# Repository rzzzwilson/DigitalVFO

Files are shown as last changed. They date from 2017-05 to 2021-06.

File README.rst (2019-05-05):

Digital VFO
===========
 
About
=====

I'm an amateur radio operator, but since I'm not in the country in which I
earned my licence I can't actually build or operate a transmitter, so I build
receivers and test gear.  I'm working on being able to operate from my
country of residence, but that's another story.

One piece of test gear that would be useful is called a Signal Generator.  This
is a piece of kit that generates a radio signal of a known frequency.  It can
also be used as a VFO (variable frequency oscillator) in a receiver.

The modern way to accurately generate an RF signal is to use the AD9851 DDS chip
which digitally generates a known frequency from a crystal source.  There are 
quite a few people offering small boards using this chip but I like the
`DDS-60 daughterboard <http://midnightdesignsolutions.com/dds60/>`_
from `Midnight Design Solutions <http://midnightdesignsolutions.com/>`_.
All I need to do is use a microcontroller to control the DDS-60 with some
sort of frequency display!

The obvious solution is to use an Arduino and the ubiquitous 16x2 display.
Since the Arduino is a little large and I hoped to put the kit into a small
case I decided to use a
`Teensy microcontroller <https://www.pjrc.com/store/teensy32.html>`_
which is programmable through the Arduino IDE.  It's about 35mm x 18mm!
It's a very capable little microcontroller and is overkill for this project,
but it's what I have at the moment.  I'm working on a
`smaller "generic" design <https://github.com/rzzzwilson/KiCad_Projects/tree/master/Iota>`_
that I can fit into any PCB projects that need smarts.

I got a couple of generic 16x2 displays from
`AliExpress <https://www.aliexpress.com/wholesale?catId=0&initiative_id=SB_20170504210259&SearchText=display+1602>`_.
I got the rotary encoder from
`the same place <https://www.aliexpress.com/wholesale?catId=0&initiative_id=AS_20170504210300&SearchText=rotary+encoder+switch>`_.

Schematic
=========

The latest code runs on this hardware arrangement:

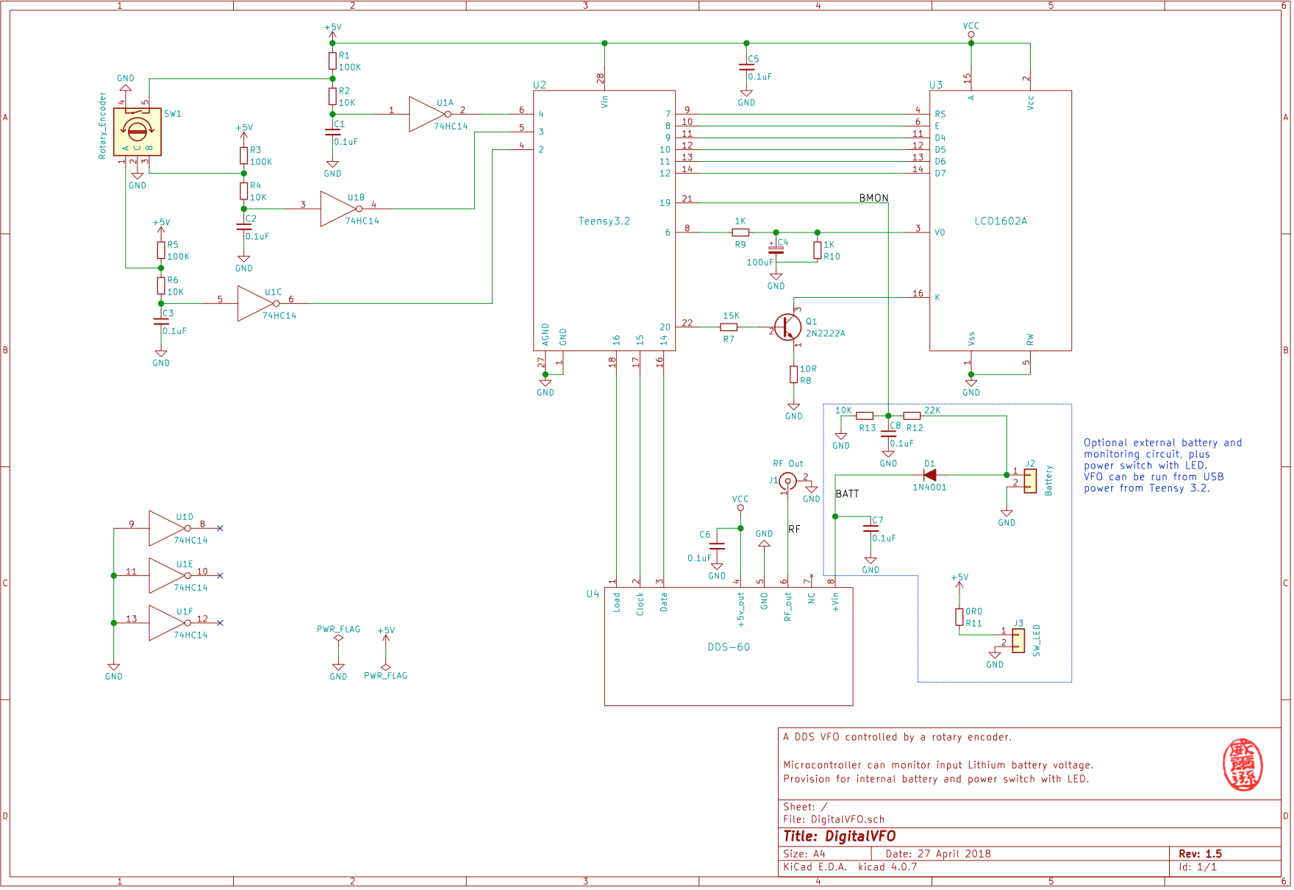
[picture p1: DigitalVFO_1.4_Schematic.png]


PCB
=========

The 1.4 PCB looks like this:

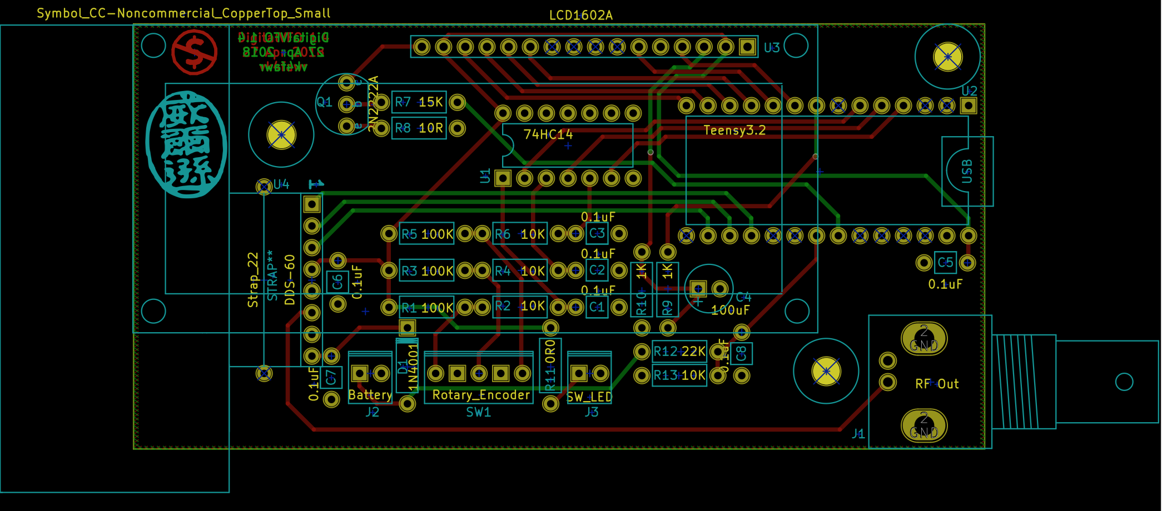
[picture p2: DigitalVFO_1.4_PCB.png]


Status
======

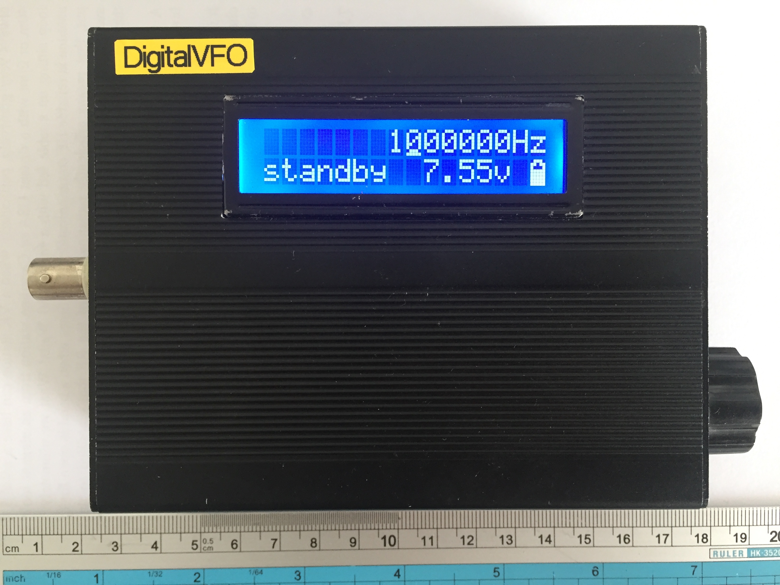
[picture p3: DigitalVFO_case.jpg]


Version 1.4 is running as shown above!  There is provision for a battery plus
monitoring of the voltage and calibration of various things.  There will be another
version called "HeadlessVFO" that will be controlled only by a PC via USB.  This
version won't need a display or rotary encoder, plus it'll always be
connected to a PC and get USB power, so no battery.  I probably don't need
a Teensy 3.2 to drive HeadlessVFO, so I'm searching for cheap microcontrollers
on AliExpress that can accept text commands from the USB connection.

13 Sept: Looking at the AtMega32U4.  A similar chip is used in the Arduino UNO
R3 instead of the FTDI FT232RL USB interface chip, but the AtMega is quite
capable and can control the HeadlessVFO so I won't need any special USB
interface chip.  Anyway, that's the current plan.

Version 1.5
===========

5 May 2019 Update
-----------------

Noted corruption of the display and things like saved frequencies.  The DDS-60
was being set to a **negative** frequency!  Investigated, but suspect this
problem was caused by interference by connecting USB power to the Teensy while
the VFO was running from the battery.  Debug by connecting USB power AT THE PC
while the VFO is off.  See if the problem reoccurs whie doing that.

Early 2019
----------

Modified the PCB layout to include test points for battery voltage, RF out, ground, etc.

Version 1.4
===========

13 September Update
-------------------

The battery arrived but it won't fit into the case.  Instead I'm using the two
18650 test cells with a small BMS PCB, all wrapped in a piece of heat-shrinkable
tubing.  I've bypassed the polarity protection diode as it eats a volt from the
battery.  Working well, but I've found that the power switch I used is a little
unreliable.  That needs to be replaced - the replacement is on a slow boat from
China.

03 July Update
--------------

Still waiting for a 7.4v battery from China.  When it arrives I'll experiment
with the monitoring software.  I may remove the 'polarity' diode once I have
cables made up.  It removes about a volt from the battery and the DDS-60 was
cutting out long before the battery was empty.

21 June Update
--------------

The case is finished.  When/if a permanent battery is installed I'll drill
a few holes for a switch and a 9v charging port.  The software for commands
from the PC is basically finished.  I removed a lot of stuff not necessary
for using the DigitalVFO in an instrument cluster.

19 May Update
-------------

The 1.4 board is back from Seeed, built and operating.  This version has
provision for the micro to sense the battery voltage so it can display
a battery symbol with full/empty options.
Software development time!

Version 1.3
===========

A redesign to use another BNC connecter as the first was junk.
Not sent to Seeed as I also decided to add battery monitoring.

Version 1.2
===========

After building the v1.1 PCB and paddling around on aliexpress.com to find
different components, I'm starting on the v1.2 PCB.  Should be smaller, have
the LCD located in a more natural place and place controls in more natural 
positions.  May also rethink the power supply - perhaps run both board and
DDS-60 from a 78L05 instead of running 9v to DDS-60 and using the onboard
regulator to generate 5v for the main board.  Use the same case as before.

29 March Update
---------------

Version 1.2 of the PCB submitted to Seeed today.  Changes were:

* moved components around to minimize vias
* on-board BNC socket, saves on internal cables
* moves Teensy to edge so USB goes through case, saves on internal cables
* added provision for internal 2s Li-Ion battery and manager PCB feeding the DDS-60
* added provision for LED power in battery power switch

Version 1.1
===========

Need to:

* new case allows in-case programming
* new case has ventilation (passive at first)
* better packaging (printed circuit board)
* better, more linear, contrast control

And, of course:

* allow control over USB
* maybe add a "sweep" function to the in-case code (from, to, step, pause)
* look for bugs in the software

With PC control we can measure things with a "sweep" function.  Allow the PC to
control the VFO frequency and the PC can sweep the frequency to whatever limits
required.  At the same time, measure voltage/current/whatever from other Teensy
instruments.  This means we could build:

* an antenna analyzer
* measure filter response curves
* etc

This version will use a printed circuit board to address the general
unreliability of the 1.0 version.  The LCD will plug into the back of the main
PCB and the DDS-60 will plug into the front.  The rotary encoder will have a
cable with header that will plug into the PCB.

The file **DigitalVFO_Schematic_1.1.pdf** is the schematic of the circuit.  The
directory **kicad/DigitalVFO/Gerbers** holds the output files produced by KiCad.
The Gerber files were sent to a Chinese PCB fab factory.

The PCB has now returned from China, and it does look good.  Better yet,
assembling the board and testing it shows the thing WORKS!  I had to change the
code to match changes I made while setting out the PCB, BUT IT WORKS!!

Version 1.0
===========

The VFO hardware is complete.  Everything is inside a small metal case.  Perhaps
too small a metal case as running at 12v the thing overheats and becomes
unreliable.  It seems OK at 9v.  I also didn't think about accessing the Teensy
USB port when the case is closed, so I can't tweak the software without cracking
the case, which I can't do often as the wiring inside is fragile.

Completed:

* Interface display to teensy, test writing, etc
* Interface rotary encoder, get rotate and button press events
* Basic display of 8-digit frequency
* Implement a simple 'event' system to produce system events
* Get frequency column select and increment/decrement working
* Save state in the EEPROM, restore state on start up
* implement a simple menu system 
* extend the menu system to allow extra functionality
* added vfo_DClick double-click event
* add code to toggle standby/ON mode (from vfo_DClick)
* add in the DDS-60 control code
* add a "Calibrate" setting to adjust the divider value in the DDS-60 code
* test the thing fully!
* make up a metal case and rebuild into it

Perhaps:

* make another case with USB access
* think about making a circuit board for it (Fritzing, cheap Chinese PCB maker?)

Ongoing:

* look for bugs in the software
* maybe add a "sweep" function to the code (from, to, step, pause)
* split out the Arduino code samples showing RE handling and menu system
* think about hardware assembly methods to make DigitalVFO version 2!

Interface
=========

I don't need a lot of functionality in this VFO, I just want to:

* set a frequency from 1.000000Mz to 30.000000MHz with steps down to 1Hz
* save and restore a number of frequencies

It should be possible to do all this with an interface made up of:

* A 16x2 display, and
* A rotary encoder, with switch.

Using the above the user can move a 'column selection' indication in the
frequency display by pressing down on the encoder knob and then rotating it.
With the knob up, rotation just increments or decrements the
selected digit with over- and under-flow occurring to the left of the
selected digit.  This is pretty much the way everybody does it.

It would also be nice if the VFO remembered the frequency and selected digit if
the power is lost and then restored.  Use the on-board EEPROM for this, as well
as remembered frequencies.

We may have to come up with some way of having a simple menu-driven method
of:

* Saving/restoring frequencies
* Adjusting various internal parameters such as clock scaling, etc.

We could possibly drop into the menu system if the encoder knob is held down
for some length of time.

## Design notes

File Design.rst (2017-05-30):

Digital VFO Design
==================

The main hardware components for the VFO are:

+-----------------+-------------------------------------------+
| Microcontroller | Controls the VFO.                         |
+-----------------+-------------------------------------------+
| Rotary encoder  | Allows the user to change VFO frequency   |
|                 | as well as save/restore frequencies, etc. |
+-----------------+-------------------------------------------+
| LCD display     | Display the VFO frequency as well as show |
|                 | the menus, etc.                           |
+-----------------+-------------------------------------------+
| DDS-60 VFO      | Generates the desired VFO frequency.      |
+-----------------+-------------------------------------------+

Operation
---------

The VFO has two modes: 'ONLINE' and 'standby'.

The displayed frequency will be changed by turning the rotary encoder knob to
the left or the right.  This will decrease and increase respectively the
frequency digit under the cursor.  Any overflow or underflow of the selected
digit will propagate to the left only.  Note that even though the displayed
frequency may change, the DDS frequency will change only if the VFO is
ONLINE.

The selection cursor will be moved left or right by pressing in and
holding the rotary encoder knob and rotating the knob to the left or right
while pressed.

The menu will be shown after the rotary encoder knob is held down for a
configurable time without rotation.  When the knob is released the menu will
be shown.  Rotating the knob left and right will navigate through menu choices.

To action a menu item press the rotary encoder knob in for a short press.

To go back one menu level just perform a long press.

Rotary Encoder interrupts
-------------------------

The rotary encoder (RE) is the heart of the VFO.  It has three pins that can
interrupt the microcontroller.  The RE code is entirely interrupt driven and the
raw hardware interrupts handled are:

+--------------+---------------------------+
| Pin          | Interrupt type            |
+==============+===========================+
| pin_A        | on rising edge            |
+--------------+---------------------------+
| pin_B        | on rising edge            |
+--------------+---------------------------+
| pin_Push     | on rising or falling edge |
+--------------+---------------------------+

The code handling these interrupts converts them into simpler logical RE events:

+--------------+------------+
| Action       | RE Event   |
+==============+============+
| Rotate left  | re_RLeft   |
+--------------+------------+
| Rotate right | re_RRight  |
+--------------+------------+
| Knob up      | re_Up      |
+--------------+------------+
| Knob down    | re_Down    |
+--------------+------------+

A further level of RE code takes the above raw RE events and adds
further logical events to get a set of VFO events:

+-------+---------------+-------------------------------------------+
| Value | Event Name    | Description                               |
+=======+===============+===========================================+
|   0	| vfo_None      | No event                                  |
+-------+---------------+-------------------------------------------+
|   1	| vfo_RLeft     | Simple rotation left while switch UP      |
+-------+---------------+-------------------------------------------+
|   2	| vfo_RRight    | Simple rotation right while switch UP     |
+-------+---------------+-------------------------------------------+
|   3	| vfo_DnRLeft   | Rotation left while switch DOWN           |
+-------+---------------+-------------------------------------------+
|   4	| vfo_DnRRight  | Rotation right while switch DOWN          |
+-------+---------------+-------------------------------------------+
|   5	| vfo_Click     | Click of the switch without rotation      |
+-------+---------------+-------------------------------------------+
|   6	| vfo_HoldClick | Held click of the switch without rotation |
+-------+---------------+-------------------------------------------+
|   7	| vfo_DClick    | Double click within a certain period      |
+-------+---------------+-------------------------------------------+

The mapping between the RE events and VFO events is explained below:

+-----------+------------------------------------------------------------------------------+
| RE Event  | Mapping to VFO events                                                        |
+===========+==============================================================================+
| re_RLeft  | If knob is up -> vfo_RLeft, if down -> vfo_DnRLeft.                          |
+-----------+------------------------------------------------------------------------------+
| re_RRight | If knob is up -> vfo_RRight, if down -> vfo_DnRRight.                        |
+-----------+------------------------------------------------------------------------------+
| re_Down   | Set internal state to 'down' and take note of the current millisecond value. |
+-----------+------------------------------------------------------------------------------+
| re_Up     | If elapsed 'down' time is short -> vfo_Click, else -> vfo_HoldClick.         |
|           | If there was any rotation while down no event posted.  Clear 'down' state.   |
|           | If a particular single click was close enough to the previous single click   |
|           | issue a vfo_DClick instead.                                                  |
+-----------+------------------------------------------------------------------------------+

The above implies that there will be internal state to the RE code encapsulating:

* switch state
* time when knob pressed

Event Queue
-----------

The RE code is entirely interrupt driven and a decision was made **not** to
directly drive the VFO logic from interrupt code.  We do this by having the RE
code generate the events above and place them into an event queue.

There will be two functions to push/pop events onto and off the queue::

    push_event(event);
    event = pop_event();

Note that the RE code will never **push** a *vfo_None* event onto the queue.
The *pop_event()* function will return a *vfo_None* event if the queue is empty.

The queue will be implemented as a circular buffer with length of about
10 events.  Note that the *pop_event()* function *must* be thread safe.
The *push_event()* function runs in the interrupt handler so is safe.

Main Event loop
---------------

There will be a main event loop within the Arduino *setup()* function to handle
most top-level interaction.  There will be some smaller event loops within some
menu action handler routines.

Menu System
===========

There will be a menu system that will allow the user to:

* Save/Restore/Delete slots.  Slots hold frequency and other information.
* Reset certain parameters that render the UI unusable, such as brightness, contrast, etc.
* Reset all slots and set configurable parameters to the defaults.
* Configure certain values for brightness, contrast, etc.
* Calibrate the VFO oscillator.
* Etc.

The menu system will have this structure::

    Menu      Slots     Save slot
                        Restore slot
                        Delete Slot
              Settings  Brightness
                        Contrast
                        Hold click
                        Double click
                        Calibrate
              Reset all No
                        Yes
              Credits

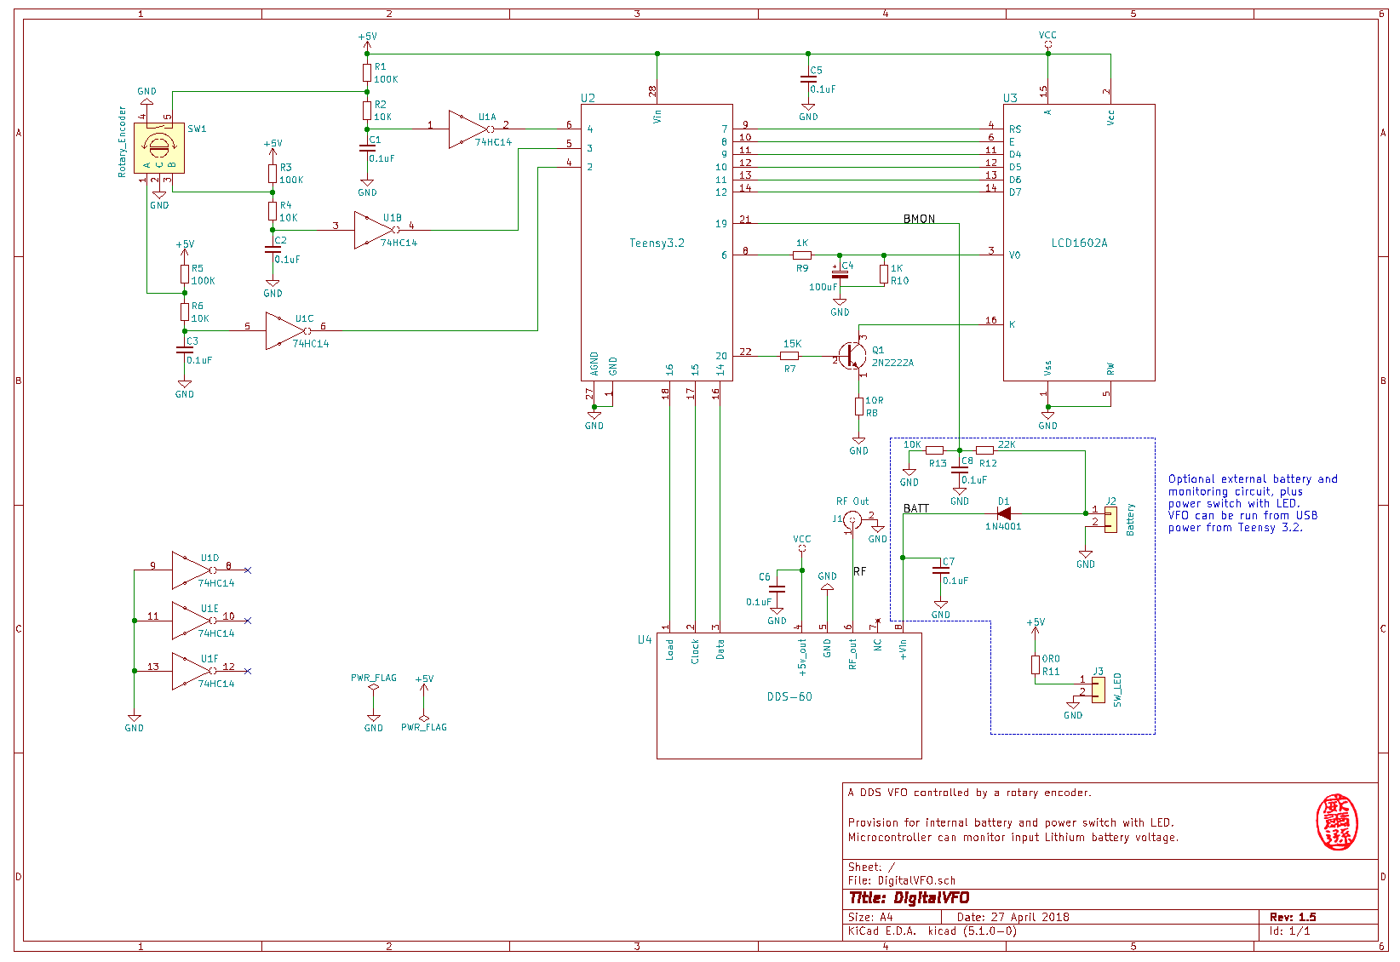
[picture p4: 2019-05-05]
DigitalVFO_1.5_Schematic.png

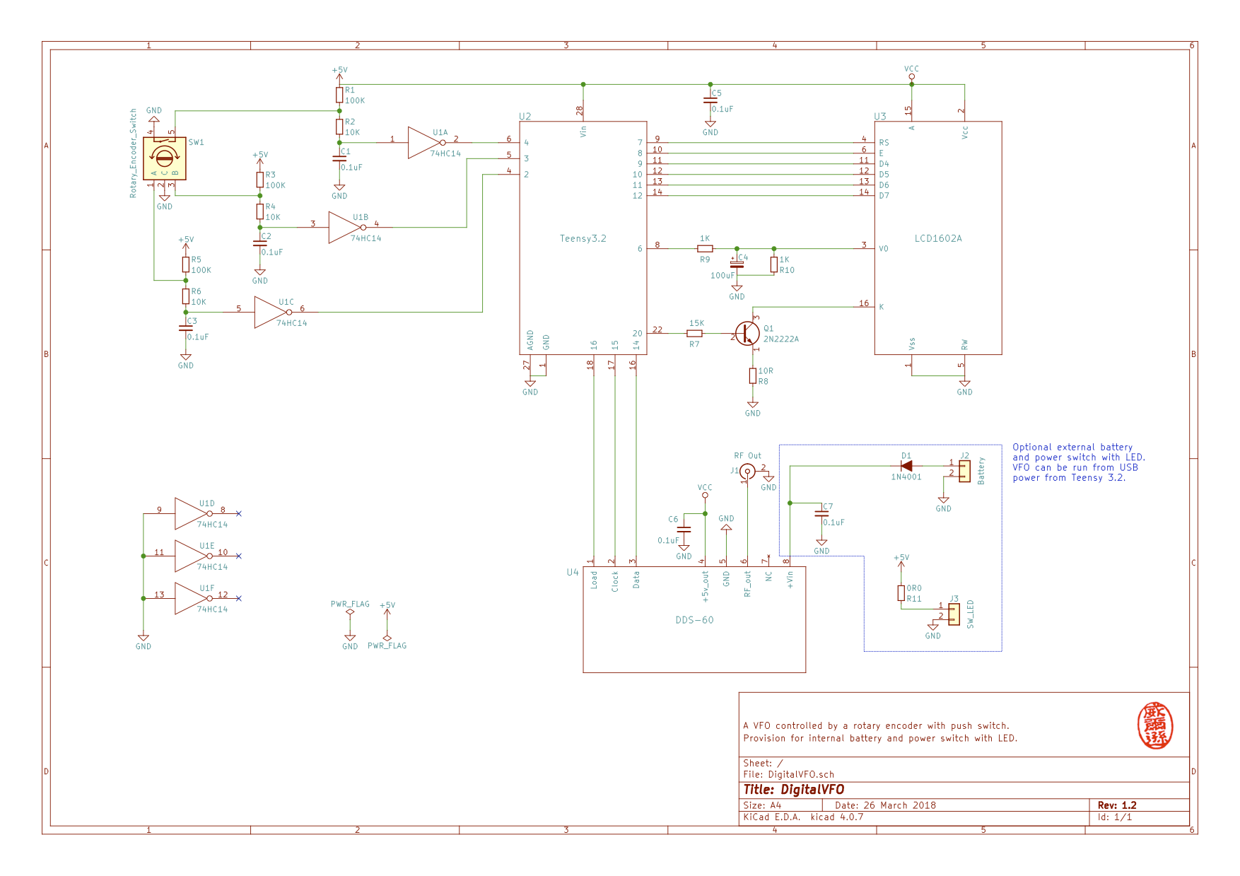
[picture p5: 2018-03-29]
DigitalVFO_1.2_Schematic.png

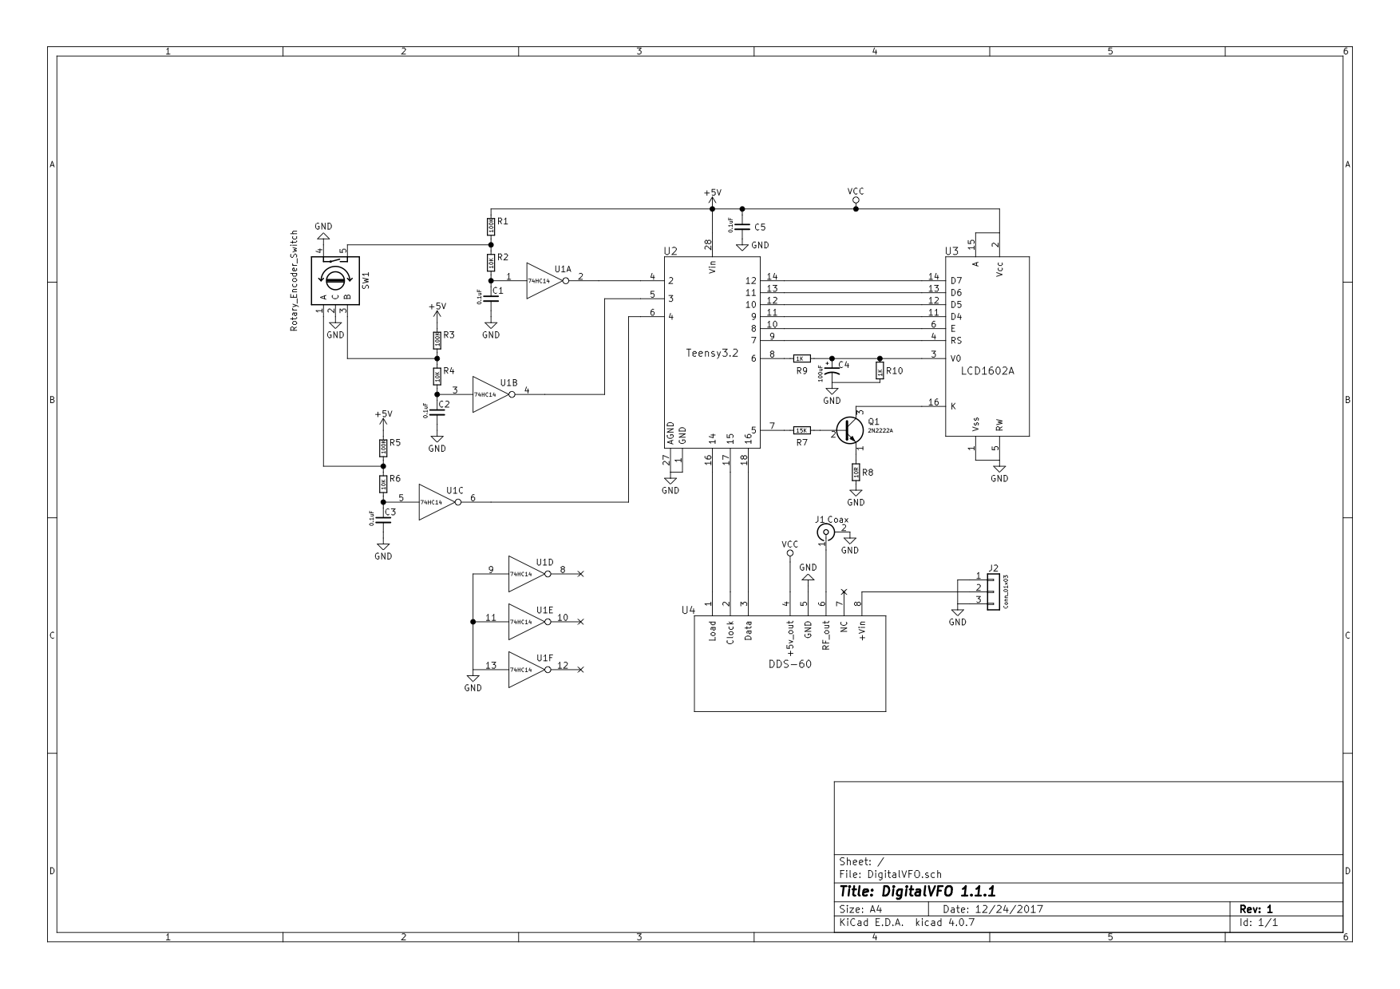
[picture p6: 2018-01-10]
DigitalVFO_1.1_Schematic.png

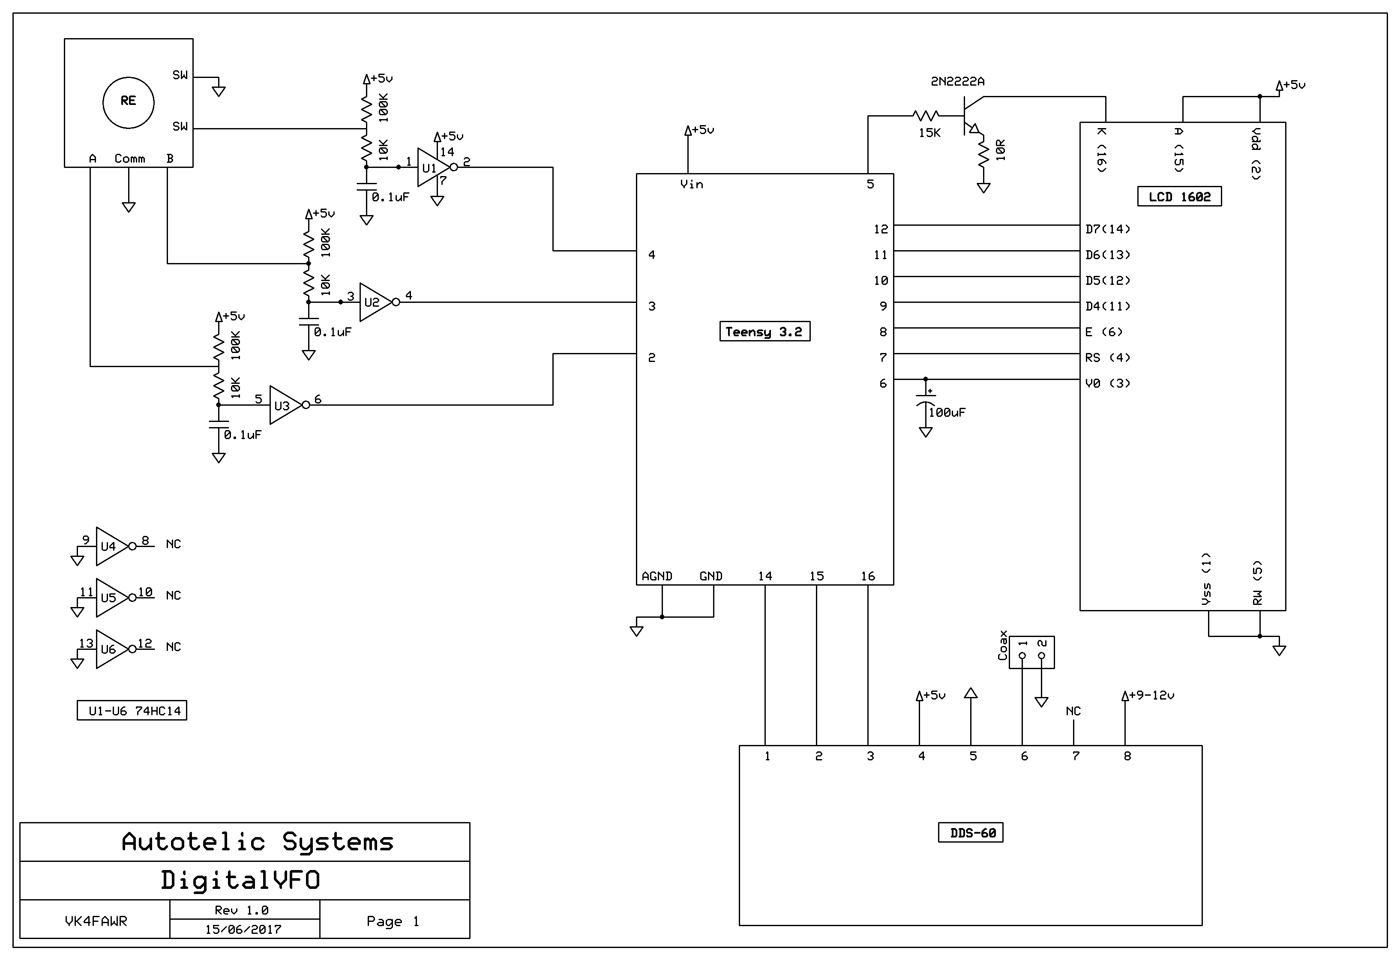
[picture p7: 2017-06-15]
DigitalVFO_1.0_Schematic.png

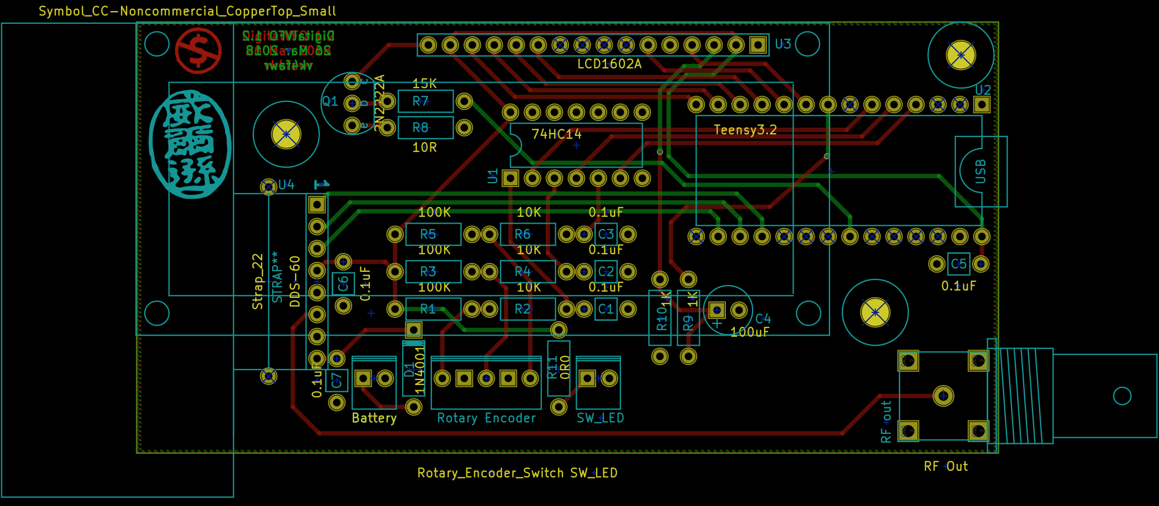
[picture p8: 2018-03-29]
DigitalVFO_1.2_PCB.png

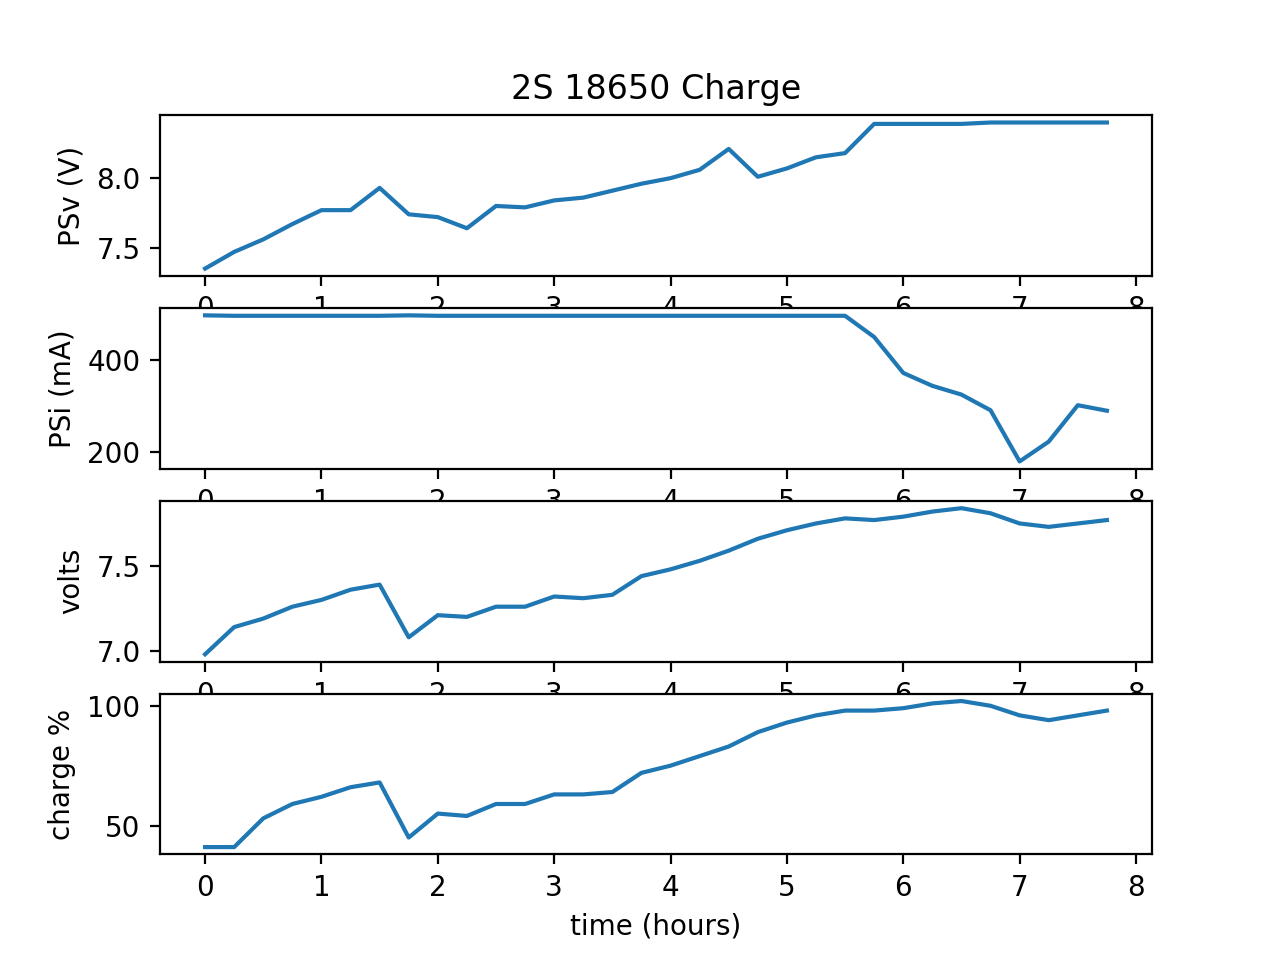
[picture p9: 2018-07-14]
pyInstrument/charge.png

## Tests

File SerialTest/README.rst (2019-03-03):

This little program is used to test communications with the early Uno clone
circuit consisting of an FT232RL/Atmega238P setup.

The code blinks the attached LED every 5 seconds.  It is also listening on
the serial port for a "command" string terminated by a ';' character.  Whenever
a complete command is read the LED is also blinked
(unless the command is "quit;").

The point is to:

* test the clone circuit
* exercise the serial port

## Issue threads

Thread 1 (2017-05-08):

HoldClick timing problem

rzzzwilson, 2017-05-08:
When first started, the program seems to obey the 500msec delay that signals that a click is really a HoldClick.  But after some usage (a few menu operations) the required delay seems to increase.  Sometimes the Teensy locks up!?

rzzzwilson, 2017-05-08:
This may have been solved by adding 0.1uF caps to the RE pins A, B and the switch.  Performs as expected now.  Close this.

Closed 2017-05-08.

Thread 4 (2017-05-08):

Extra menu functionality?

rzzzwilson, 2017-05-08:
With the basic menu system now working, what else can we do in the menus?

* adjust display contrast/brightness (may require that a control transistor or two  be added)
* adjust HoldClick timing
* choose programmed sweep functions (triangle, saw, ...)
* ?

rzzzwilson, 2017-05-09:
Added "delete save/restore slot" menu.

rzzzwilson, 2017-05-10:
Put the menu for settings/contrast in (see issue #5).  Raise another issue to revisit the menu-handling code, it's messy!

rzzzwilson, 2017-05-16:
Contrast and brightness now changeable.  Required adding big electro capacitor to a PWM line to control brightness.

rzzzwilson, 2017-05-19:
VFO now has 'modes': Standby and Online.  Controlled by a double-click on the main screen.

rzzzwilson, 2017-05-20:
Calibrate mode forces VFO into online mode during calibration.

rzzzwilson, 2019-05-05:
Added calibration of the measured battery voltage.

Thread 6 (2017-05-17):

Different startup option

rzzzwilson, 2017-05-17:
Currently if there is a HoldClick during the banner presentation we reset brightness/contrast, etc.  This doesn't work in VFO_DEBUG mode as we don't show the banner.

A better approach is to sense if the RE button is down during startup.  If so, reset stuff that can disable using the VFO, such as:

* brightness
* contrast
* HoldClick time

rzzzwilson, 2017-05-18:
Done.

Closed 2017-05-18.

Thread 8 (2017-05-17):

Better console handling

rzzzwilson, 2017-05-17:
Instead of using bare Serial.print() calls, write `log()` functions:

* log(int)
* log(char *)
* logln(int)
* logln(char *)

Shorter code in the body and more centralized control - we can turn off logging in 4 places.
Or maybe we can use C macros?

rzzzwilson, 2017-05-18:
No, didn't do this due to limited C compiler features.

Did switch to using Serial.printf() though.

Closed 2017-05-18.

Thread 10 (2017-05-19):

Should use 'latch' in main screen

rzzzwilson, 2017-05-19:
In the current implementation we adjust the DDS-60 frequency every time the rotary encode rotates.  That's fine and could be useful, **but** we also write the new frequency to EEPROM.  That could be a problem as we have limited writes before the EEPROM becomes flakey.

Change the approach to a 'latch' system.  The display will show the actual DDS-60 frequency on the top row, as before.  Below that we will have a *second* frequency display which the RE will manipulate as before.  Doing a VfoClick event will latch the bottom frequency into the top display and the DDS-60 frequency will be updated and the EEPROM will be written.

rzzzwilson, 2017-05-19:
The teensy doc seems to suggest that we have a limit of 13,000,000 writes (with wear levelling), so do we need to worry about this?

rzzzwilson, 2017-05-19:
Another alternative is to **not** save every VFO frequency change, but just use the slots.  On startup we would display a default frequency and the user would restore from a slot.

If we ever have a "standby" mode that will be the default start mode.

rzzzwilson, 2017-05-24:
We solved this by having a 'standby' mode and an 'ONLINE' mode.  Only update frequency of right/left RE movement in ONLINE mode.

Closed 2017-05-24.

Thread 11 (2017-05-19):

Implement RE double-click?

rzzzwilson, 2017-05-19:
We need to be able to put the VFO into "standby" mode where it keeps the oscillator warm but has no output.  There is no way (beyond a menu item) to control this.

Look into implementing a "double-click" (VfoDClick) in the RE code.  There will have to be a timer in the code, possibly using the HoldClick timing or a separate timer value.

If the VfoDClick is viable, allow the main event handler to see that and toggle the VFO state to active or standby as appropriate.  Put a text display on the start of line 2 showing "ON" or "Standby".

rzzzwilson, 2017-05-19:
Done and works well.

Closed 2017-05-19.

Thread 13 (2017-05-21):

Contrast depends on voltage supply

rzzzwilson, 2017-05-21:
When operating off USB power, the 5v rail runs at 4.47v.  When off the 12v supply the 5v rail is 5.15v?  The difference is that when on 12v power the 5V regulator on the DDS-60 provides the teensy 5v rail.

Don't really care, but the contrast control voltage is 4.07v on USB power and 4.44v on 12v power.  This leads to an appreciable contrast difference.

Since we will usually operate on 12v power, does this matter?

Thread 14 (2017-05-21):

"Reset" startup leaves screen at in menu, not main screen

rzzzwilson, 2017-05-21:
If starting with the RE button down, we get the rest as required, but the interface goes into the menu.  Should go to the main screen.  Possibly leaving a HoldClick in the event queue.

rzzzwilson, 2017-05-24:
Fixed, poor handling of 'reset' code at beginning.

Closed 2017-05-24.

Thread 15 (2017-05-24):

Check if going online sets frequency

rzzzwilson, 2017-05-24:
Since changing the way the main screen works (standby/ONLINE) make sure that we update the VFO frequency only when going ONLINE.  This also means we write the VFO frequency to EEPROM less frequently.

Also when the VFO starts up it should set the display to the saved VFO frequency.  That is, if the display frequency hasn't been written to EEPROM it's lost on power down.

rzzzwilson, 2017-05-24:
Fixed.

Closed 2017-05-24.

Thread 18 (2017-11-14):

Convert PWM contrast control to analog

rzzzwilson, 2017-11-14:
As the title says.

rzzzwilson, 2017-11-20:
No, not going to do this.  There is a DAC output on the Teensy 3.2 that will output a true analog voltage, but that's on a new A14 pin that isn't in the DIP-28 pins.  It's on a new pin at the end of the Teensy board so it's too hard to fit into the packaging.

I did add some hardware smoothing (1k+100uF RC smoothing) to the circuit and re-jigged the contrast handling.

Closed 2017-11-20.

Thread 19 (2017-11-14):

Make new case

rzzzwilson, 2017-11-14:
A new case with:

- [x] better ventilation
- [x] in-case programming/control
- [x] built-in battery

A larger not-so-tight-fit case may solve the overheating problem.  Could add a small 5v fan, if required.

Lead a USB extension from the Teensy to a hole in the case.

rzzzwilson, 2018-05-23:
The case lives!

Tested with a couple of 18650 Li-Ion cells.  Wait for the AliExpress battery with better form factor.  Then need to calibrate the battery display.  Think about removing the protection diode in the battery input.  Also need to add a power button when the battery is built in.

rzzzwilson, 2018-08-12:
All done.  Seems stable.

Closed 2018-08-12.

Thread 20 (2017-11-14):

Allow external control through USB

rzzzwilson, 2017-11-14:
We program via bootloader and the USB connection.  Allow (somehow) to maintain the ability to reprogram but also allow the running VFO to be controlled/interrogated via USB.

This would allow more sophisticated things to be added externally before perhaps putting the functionality into firmware.  Things like:

* a sweep function
* antenna analyzer
* etc

rzzzwilson, 2018-01-14:
This has been done.  Commands implemented are:

* "MSO;" - set VFO mode to 'online'
* "MSS;" - set VFO mode to 'standby'
* "MG;" - get VFO mode
* "FSnnnnnnnn;" - set frequency to 'nnnnnnnn'
* "FG;" - get frequency
* "CSn;" - set cursor to index 'n'
* "CG;" - get cursor index
* "DS+n;" - increment frequency digit by 'n'
* "DS-n;" - decrement frequency digit by 'n'

rzzzwilson, 2018-01-14:
What needs to be done now is to allow control of **multiple** teensy devices through USB.  This means a python program will need to enumerate USB devices and identify each one.  Different command sets will be used for different teensy controlled devices.

But that's a problem for the python controller.

Closed 2018-01-14.

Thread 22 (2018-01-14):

Memory usage

rzzzwilson, 2018-01-14:
The code uses Serial.printf() heavily as it reduces the number of lines to produce the desired output.  But the "printf" library is heavyweight.

By replacing the *Serial.printf()* calls with just *Serial.print()* calls memory usage can be reduced from 41860/5936 bytes of program/global usage to 24852/5572.  Despite the verbose addition of **lots** of Serial.print() calls!

Keep this in mind if memory gets short.

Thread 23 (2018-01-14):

PCB Changes

rzzzwilson, 2018-01-14:
When making a new PCB, consider:

- [x] Rotating RF socket 90 degrees for better side clearance
- [x] Making a large "ground area" for DSO probe ground connection
- [x] Adding single test point pads, ground and other signals
- [x] Make PCB smaller

rzzzwilson, 2018-05-20:
With version 1.4 of the PCB, most of this is done, with the exception of test points.

rzzzwilson, 2018-05-20:
PCB version 1.5 has all the desired features.

Closed 2018-08-12.

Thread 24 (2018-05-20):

DDS-60 not setting correctly

rzzzwilson, 2018-05-20:
With the 1.4 version of code + PCB, the DDS frequency is not being set properly.  That is, the frequency emitted by the DDS-60 is NOT what is displayed on the screen.

rzzzwilson, 2018-05-20:
Not sure what I changed (if anything), but DDS-60 is now producing approx the correct frequency.

Closed 2018-05-20.

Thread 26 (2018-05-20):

Serial prints truncated

rzzzwilson, 2018-05-20:
When starting the Teensy after a code download (or just power up) the largish print is truncated apparently without any ill-effects to DigitalVFO operation.  For example, this is a truncated display:

```
DEBUG is defined as 00000B:
    DEBUG_DDS	bit is set
    DEBUG_FREQ	bit is set
    DEBUG_EVENT	bit is set
DDS into standby mode.
dds_update: frequency=0

*************************************************
*           DigitalVFO 1.4.0 (vk4fawr)          *
*************************************************

=================================================
dump_eeprom: VfoFrequency=-1293967296
             AddressSelDigit=6
             VfoClockOffset=1500
             LcdBrightness=143
             LcdContrast=130
             ReHoldClickTime=500msec
             ReDClickTime=300msec
Slot 0: freq=-993967296, seldidone.
Ready!
```

Note that the second last line starts to show the contents of slot 0, but is truncated.  And the other 9 slots don't show at all!

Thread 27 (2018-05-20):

Allow setup for Max/Min battery voltages

rzzzwilson, 2018-05-20:
The code can now measure the battery voltage and display an empty/full battery symbol.  The max/min voltages for full/empty are currently hard-coded.  Allow the user to set these voltages in the "Settings" menu, since that actual voltage limits will vary according to resistor tolerance, different battery chemistries, etc.

rzzzwilson, 2018-05-21:
We can either change the builtin full/empty voltages or leave them set for the battery chemistry and instead change the voltage divider maths.  We could just change one of the divider resistor values.  Eg, "32000" as the calibration value.  This is easier to implement than two voltages or a fractional ratio.

rzzzwilson, 2019-05-05:
This has been done, using a "voltage calibration" similar to that for frequency.

Closed 2019-05-05.

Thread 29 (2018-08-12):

Reduce power usage

rzzzwilson, 2018-08-12:
Look at reducing power usage by sleeping the CPU after a timeout (configurable).

Some data:

https://github.com/duff2013/Snooze
https://forum.pjrc.com/threads/53268-Sleep-code-Teensy-3-2

rzzzwilson, 2019-05-05:
Most power is taken up by the display and DDS-60, so try to:

* display "sleep" after configurable time
* ensure DDS-60 minimum current if not online
* finally, look at CPU savings, turn on display on interrupt, etc

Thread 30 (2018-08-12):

Better frequency display

rzzzwilson, 2018-08-12:
Try to display the frequency as:

**2,123,245Hz**

This requires changes to the code to display the frequency as well as the RE code to increment digits of the frequency.  Also look at the code to manipulate the "calibrate" value as this uses a similar method of changing the calibrate value.

Try to have one body of code to handle all usages.  Will need to be data-driven, eg, array of char offsets for each digit being adjusted, max number of digits to handle, etc.

rzzzwilson, 2020-04-21:
Done.

Closed 2020-04-21.

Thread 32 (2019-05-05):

Corruption?

rzzzwilson, 2019-05-05:
When using the VFO, the display can become corrupted:

* frequency wraps around to 99MHz
* with 1,000,000 displayed, decrement (at leftmost "1") gets BLANK frequency display
* DDS-60 signal shows RANDOM changing frequency when offline

I suspect this may have been triggered when plugging in the USB power while the battery is ON.  Might have been better to have USB power disconnect battery.

rzzzwilson, 2019-07-06:
I have found a reliable method of producing the "corruption":

* Turn on DigitalVFO, remembered frequency id `1000000Hz`
* Move cursor one position to the right
* Increment position by one
* Move two position to the left (space)
* Decrement one click, shows `86067296Hz`

The corrupted frequency is always `86067296Hz`.  If you move *two* spaces right before incrementing then the corrupted frequency is `85977296Hz`.  Three, it's `85968296Hz`, etc.

The corruption doesn't occur if you only do the last two steps (ie, move left to space and decrement).

rzzzwilson, 2020-04-06:
Found to be improper handling of decrementing the VFO frequency.

Closed 2020-04-06.

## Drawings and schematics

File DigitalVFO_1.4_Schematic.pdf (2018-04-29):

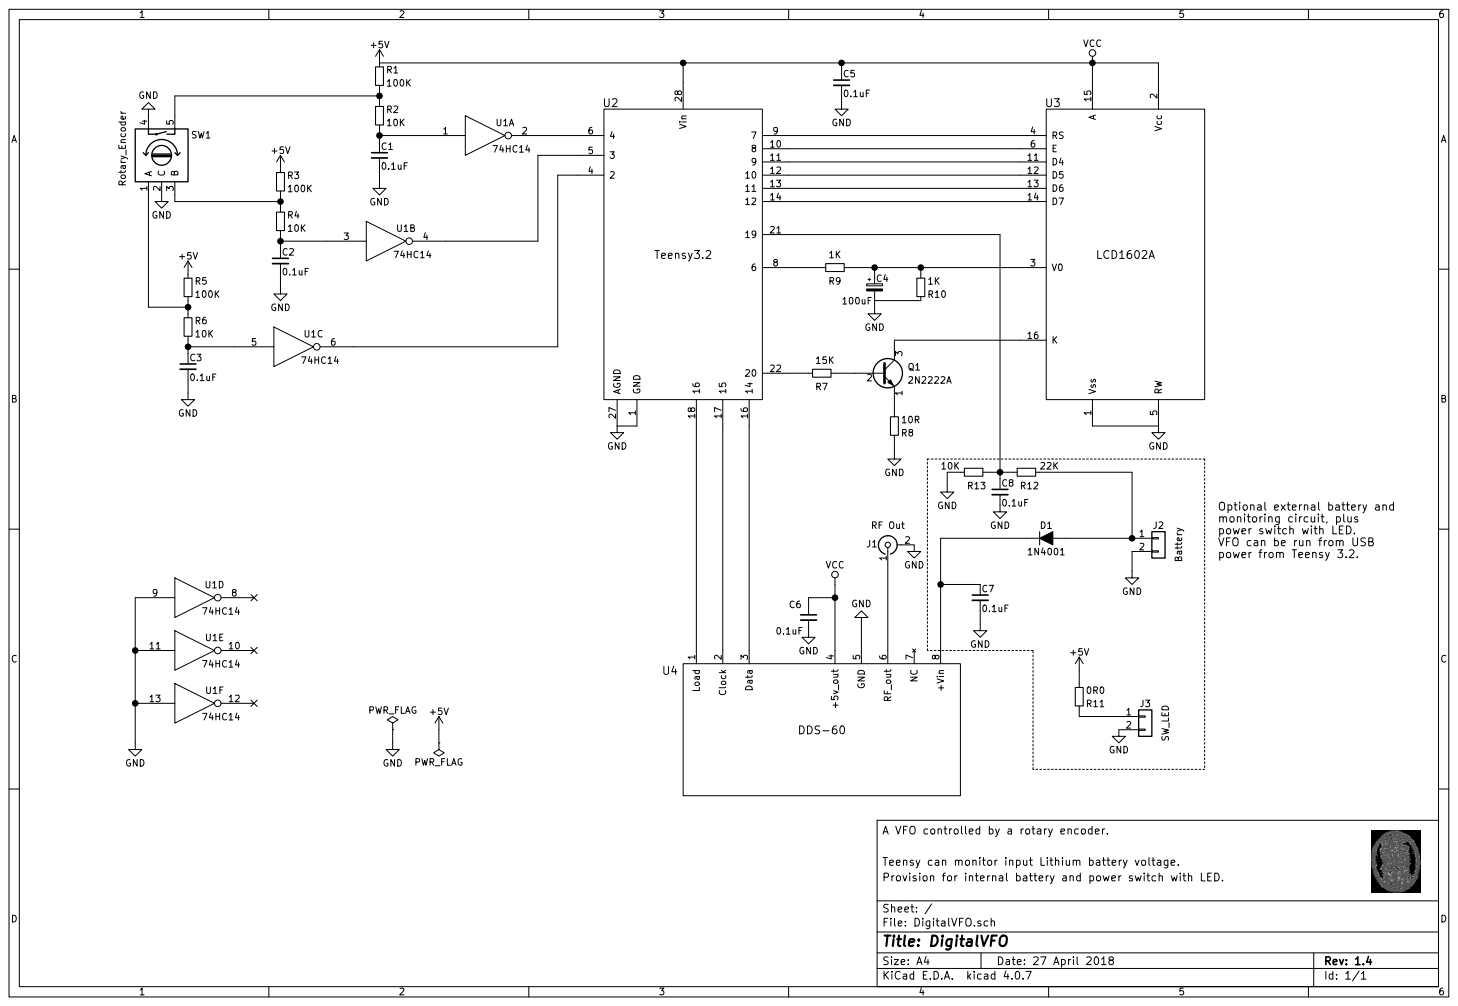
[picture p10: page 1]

monitoring circuit, plus
power switch with LED.
VFO can be run from USB

A VFO controlled by a rotary encoder.

Teensy can monitor input Lithium battery voltage.
File: DigitalVFO.sch Sheet: / Provision for internal battery and power switch with LED.

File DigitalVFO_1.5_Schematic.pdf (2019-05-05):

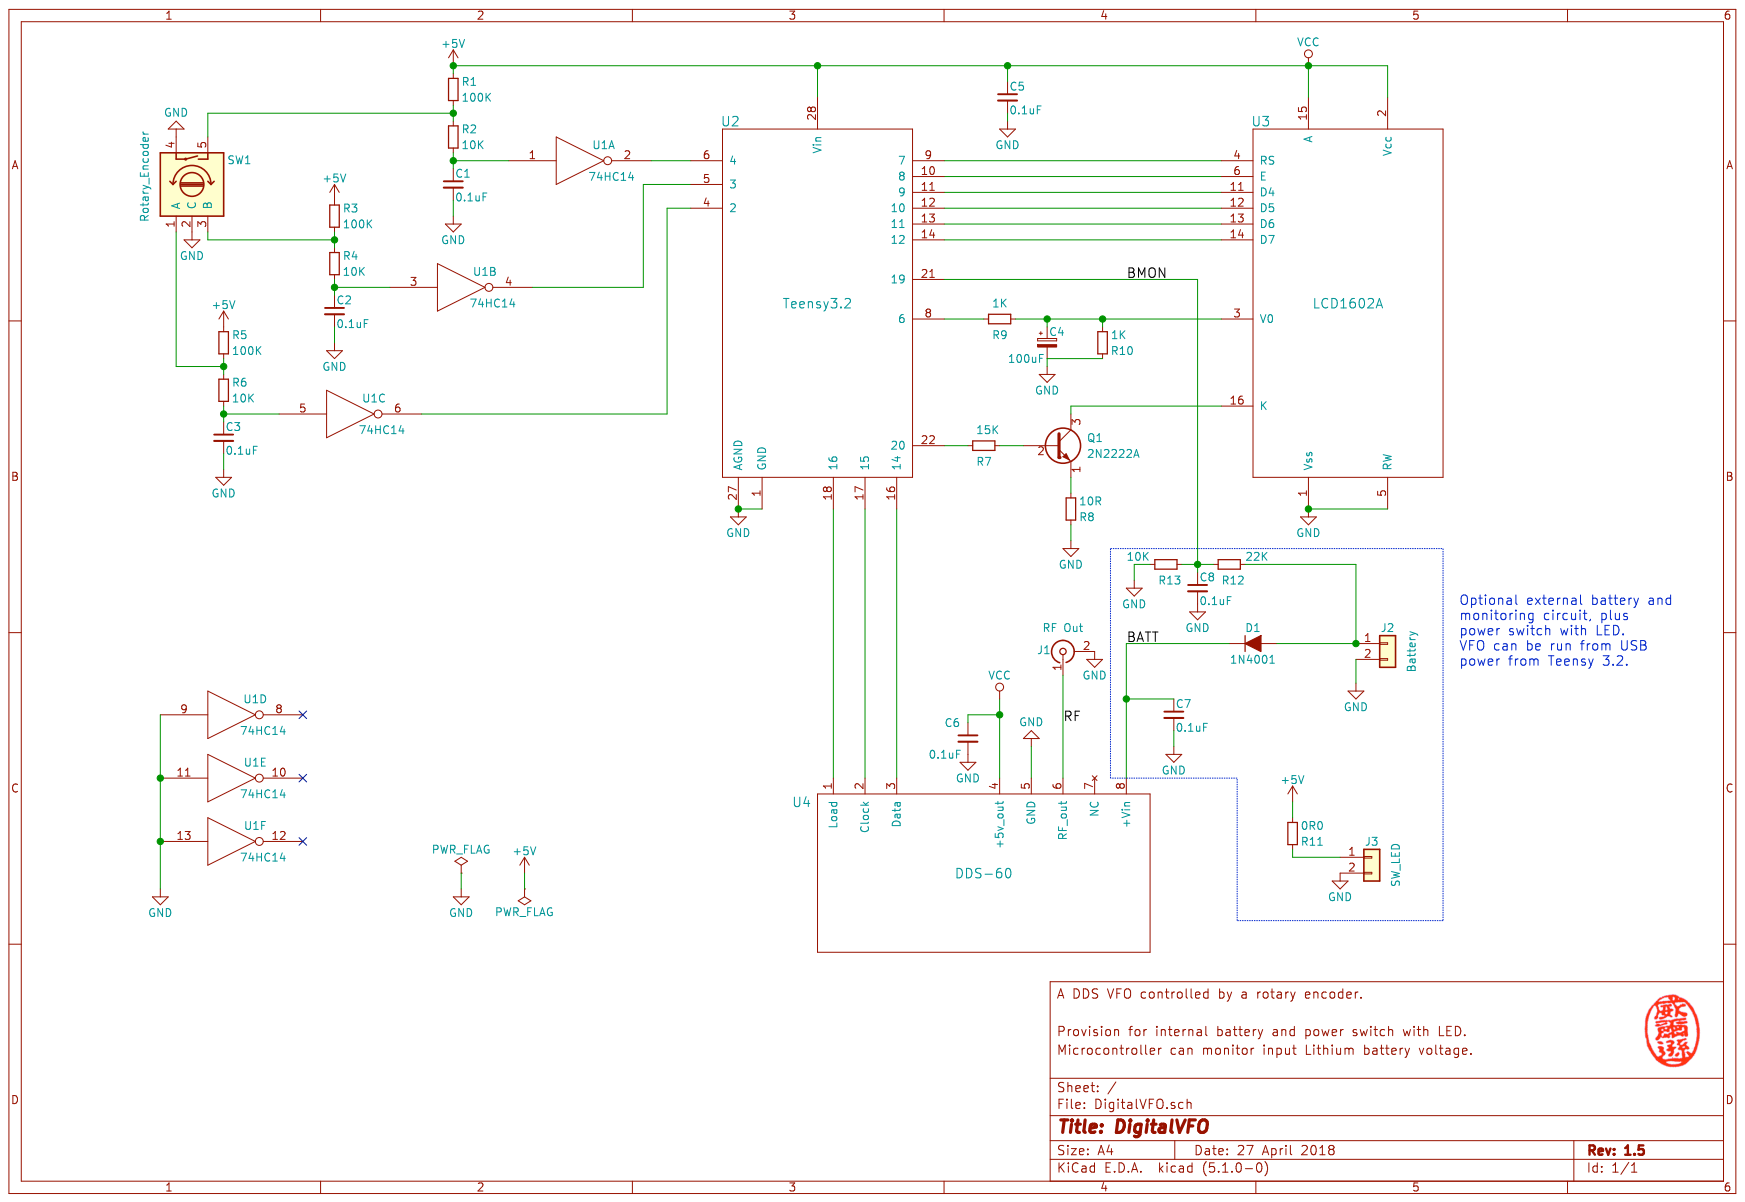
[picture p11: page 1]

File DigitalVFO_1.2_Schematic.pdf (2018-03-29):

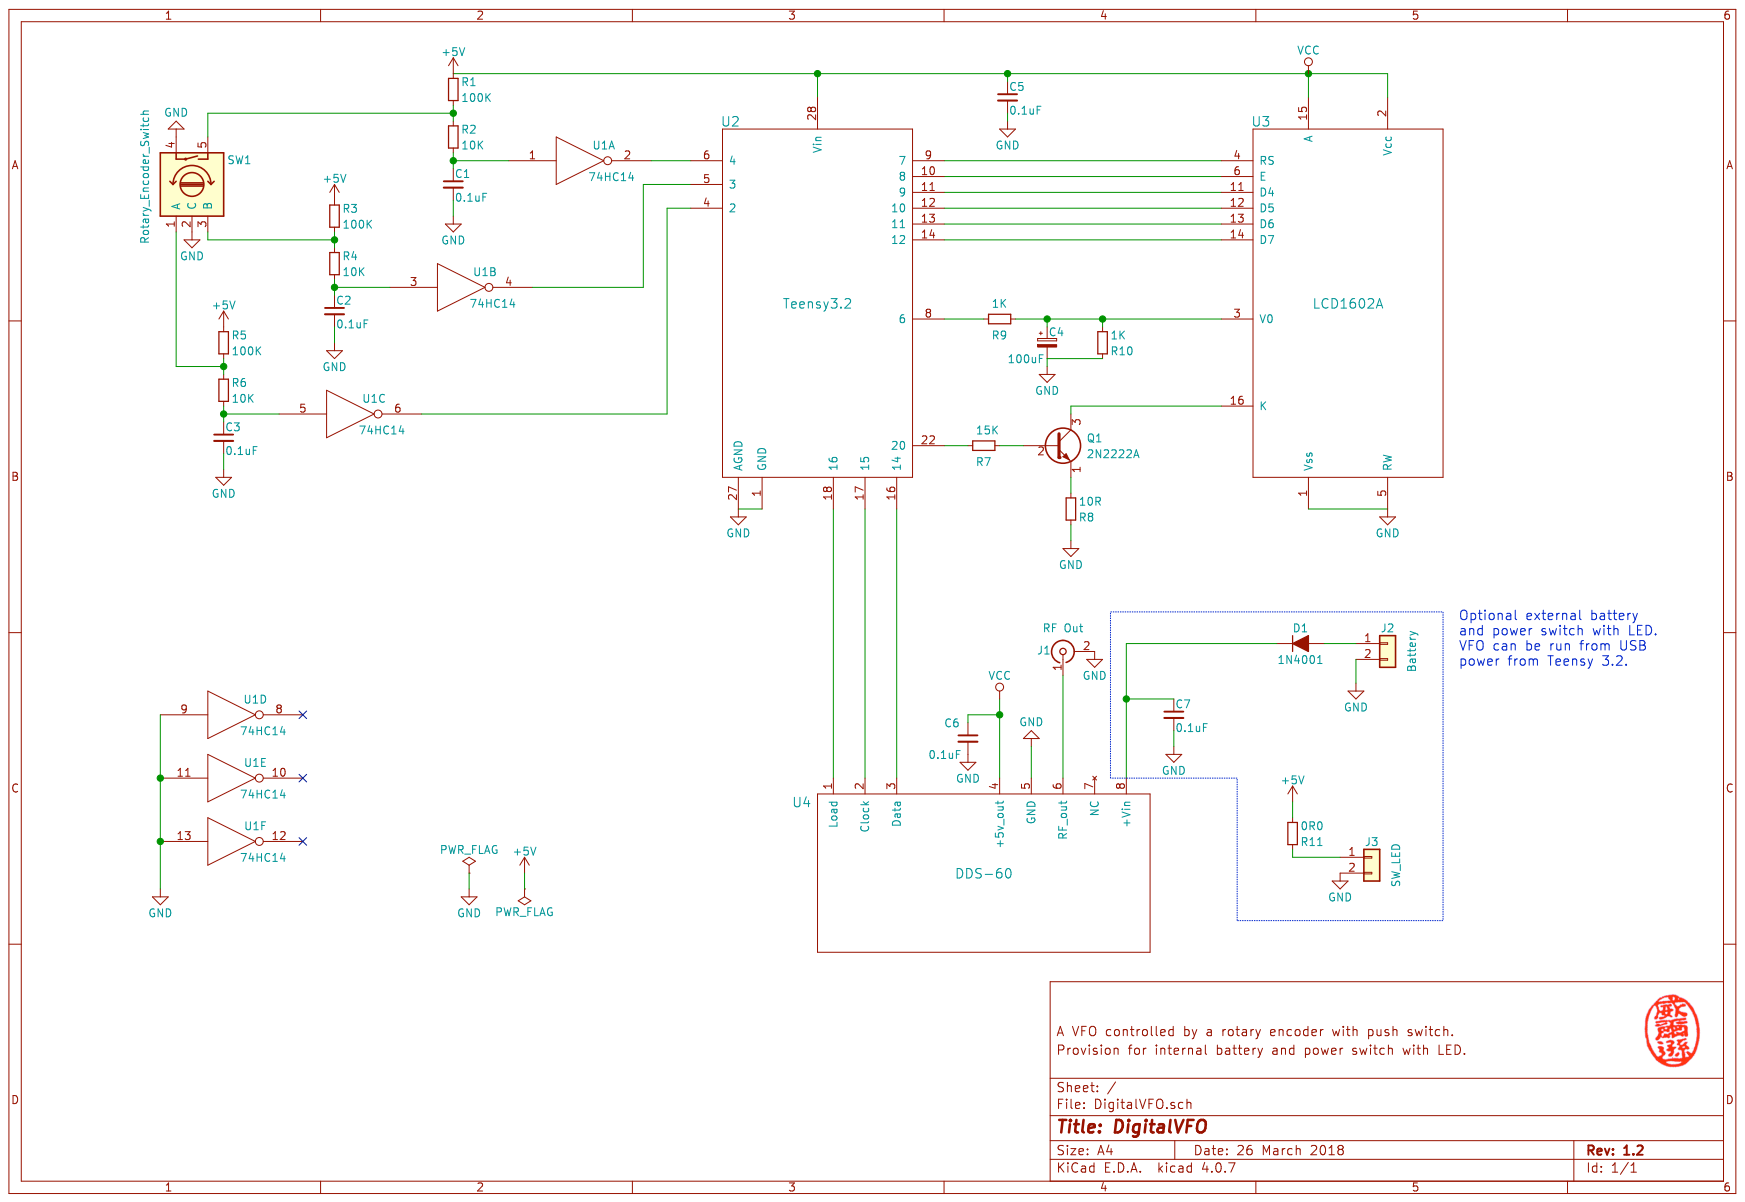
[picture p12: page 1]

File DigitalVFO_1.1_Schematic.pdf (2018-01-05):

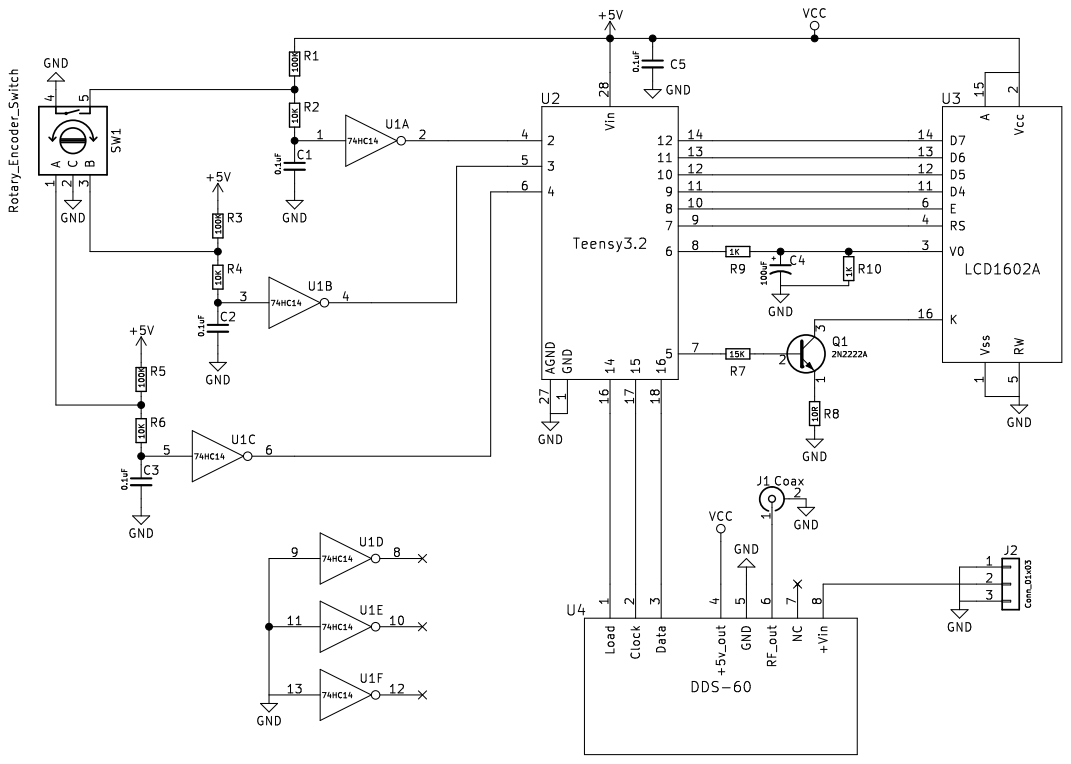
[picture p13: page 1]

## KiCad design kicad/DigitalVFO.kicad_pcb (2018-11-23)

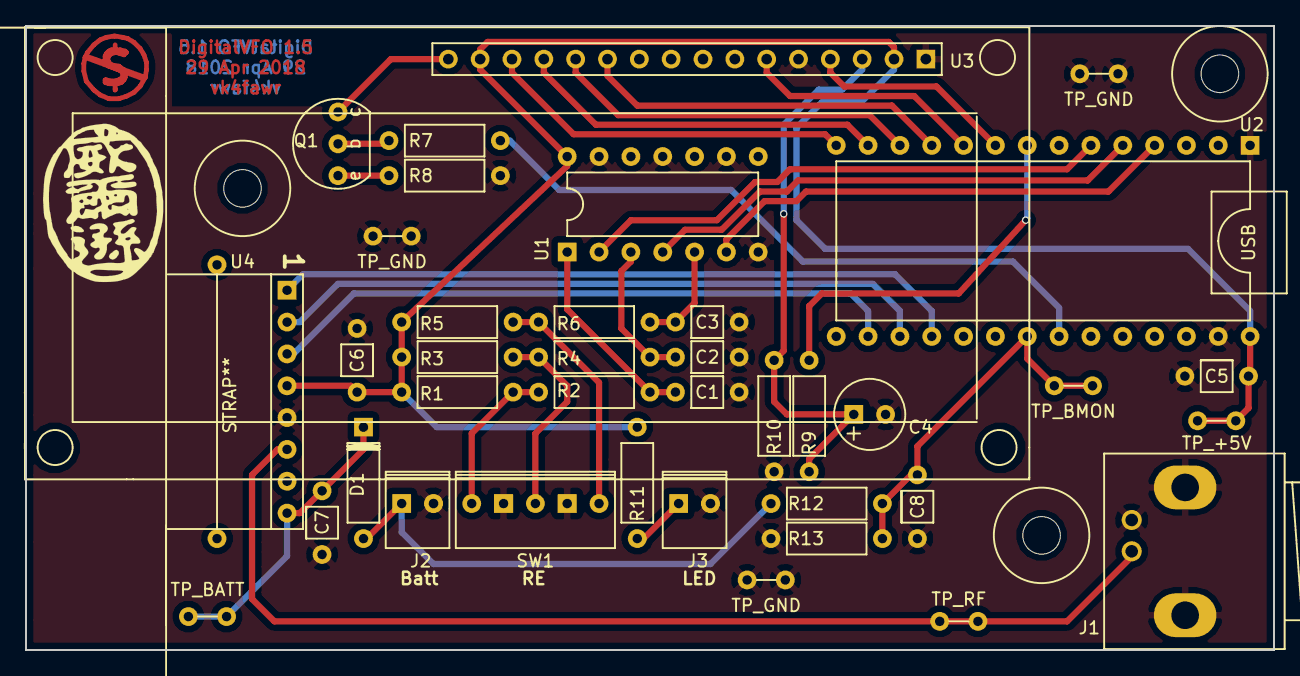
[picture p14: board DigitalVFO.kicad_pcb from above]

Board: 2 copper layers, 99.6 x 49.8 mm, 39 parts (0 on the bottom side), 31 nets.

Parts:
C1, C2, C3, C5, C6, C7, C8: 0.1uF; Cap_SmV
C4: 100uF; Conn_CElec_v
D1: 1N4001; Diode_SmH
J1: RF Out; BNC_Socket_TYCO-AMP
J2: Battery; Conn_Power_2
J3: SW_LED; Conn_Power_2
Q1: 2N2222A; Con_2N222A
R1, R3, R5: 100K; Res_SmH
R2, R4, R6, R13: 10K; Res_SmH
R7: 15K; Res_SmH
R8: 10R; Res_SmH
R9, R10: 1K; Res_SmH
R11: 0R0; Res_SmH
R12: 22K; Res_SmH
STRAP**: Strap_22
SW1: Rotary_Encoder; Conn_RE_Switch
TP_+5V: TestPoint
TP_BATT: TestPoint
TP_BMON: TestPoint
TP_GND: TestPoint
TP_GND#2, TP_GND#3: TestPoint
TP_RF: TestPoint
U1: 74HC14; Conn_DIP14n
U2: Teensy3.2; Conn_DIP28w
U3: LCD1602A; Conn_LCD16
U4: DDS-60; Conn_DDS8

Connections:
+5V: C5.1, C6.1, R1.1, R3.1, R5.1, R11.1, TP_+5V.1, TP_+5V.2, U1.14, U2.28, U3.2, U3.15, U4.4
/BATT: C7.1, D1.1, TP_BATT.1, TP_BATT.2, U4.8
/BMON: C8.1, R12.2, R13.1, TP_BMON.1, TP_BMON.2, U2.21
/RF: J1.1, TP_RF.1, TP_RF.2, U4.6
GND: C1.2, C2.2, C3.2, C4.2, C5.2, C6.2, C7.2, C8.2, J1.2, J2.2, J3.2, R8.2, R10.2, R13.2, SW1.2, SW1.4, TP_GND.1, TP_GND.2, TP_GND#2.1, TP_GND#2.2, TP_GND#3.1, TP_GND#3.2, U1.7, U1.9, U1.11, U1.13, U2.1, U2.27, U3.1, U3.5, U4.5
unnamed: C1.1, R2.2, U1.1
unnamed: C2.1, R4.2, U1.3
unnamed: C3.1, R6.2, U1.5
unnamed: C4.1, R9.1, R10.1, U3.3
unnamed: D1.2, J2.1, R12.1
unnamed: J3.1, R11.2
unnamed: Q1.1, R8.1
unnamed: Q1.2, R7.1
unnamed: Q1.3, U3.16
unnamed: R1.2, R2.1, SW1.5
unnamed: R3.2, R4.1, SW1.3
unnamed: R5.2, R6.1, SW1.1
unnamed: R7.2, U2.22
unnamed: R9.2, U2.8
unnamed: U1.2, U2.6
unnamed: U1.4, U2.5
unnamed: U1.6, U2.4
unnamed: U2.9, U3.4
unnamed: U2.10, U3.6
unnamed: U2.11, U3.11
unnamed: U2.12, U3.12
unnamed: U2.13, U3.13
unnamed: U2.14, U3.14
unnamed: U2.16, U4.3
unnamed: U2.17, U4.2
unnamed: U2.18, U4.1

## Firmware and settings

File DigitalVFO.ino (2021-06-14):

////////////////////////////////////////////////////////////////////////////////
// A digital VFO using the DDS-60 card.
//
// The VFO will generate signals in the range 1.000000MHz to 60.000000MHz
// with a step ranging down to 1Hz.
//
// The interface will be a single rotary encoder with a built-in pushbutton.
// The frequency display will have a 'selected' digit which can be moved left
// and right by pressing the encoder knob and twisting left or right.
// Turning the encoder knob will increment or decrement the selected digit by 1
// with overflow or underflow propagating to the left.
////////////////////////////////////////////////////////////////////////////////

#include <string.h>
#include <LiquidCrystal.h>
#include <EEPROM.h>

//-----------------
// #defines controlling configuration
// set to "1" to turn on feature
//-----------------

// Defining this to be '1' ERASES EVERYTHING IN EEPROM
#define INIT_EEPROM   0

// show voltage on screen next to battery symbol, if symbol displayed
#define SHOW_VOLTAGE  1

//-----------------
// debug bit masks
//-----------------
#define DEBUG_DDS     (1 << 0)  // DDS debug
#define DEBUG_FREQ    (1 << 1)  // frequency stuff
#define DEBUG_MENU    (1 << 2)  // menu
#define DEBUG_EVENT   (1 << 3)  // virtual events
#define DEBUG_ACT     (1 << 4)  // actions
#define DEBUG_RE      (1 << 5)  // rotary encoder
#define DEBUG_INT     (1 << 6)  // interrupts
#define DEBUG_DISP    (1 << 7)  // display
#define DEBUG_BATT    (1 << 8)  // battery
#define DEBUG_MISC    (1 << 9)  // usually debugging

// DEBUG word for debugging program - bitmask values
//#define DEBUG         (DEBUG_BATT + DEBUG_ACT)
#define DEBUG         0

// Digital VFO program name & version
const char *ProgramName = "DigitalVFO";
const char *Version = "1.7";
const char *MinorVersion = ".2";
const char *Callsign = "ac3dn";

// display constants - below is for ubiquitous small HD44780 16x2 display
const int LcdNumRows = 2;
const int LcdNumCols = 16;

//-----
// Some convenience typedefs
//-----

typedef unsigned long ULONG;
typedef unsigned int UINT;

enum Mode 
{
  vfo_Standby,
  vfo_Online
};

enum Mode VfoMode;          // VFO mode

typedef long Frequency;
Frequency VfoFrequency;     // VFO frequency (Hz)

typedef int SelOffset;

//-----
// Pins used by microcontroller to control devices.
//-----

// define microcontroller data pins we connect to the LCD
const byte lcd_RS = 7;
const byte lcd_ENABLE = 8;
const byte lcd_D4 = 9;
const byte lcd_D5 = 10;
const byte lcd_D6 = 11;
const byte lcd_D7 = 12;

// define the display connections
LiquidCrystal lcd(lcd_RS, lcd_ENABLE, lcd_D4, lcd_D5, lcd_D6, lcd_D7);

// define microcontroller pins controlling brightness and contrast
const byte mc_Brightness = 20;
const byte mc_Contrast = 6;

// define microcontroller pin that monitors battery voltage
const byte mc_BattVolts = 19;

// define microcontroller pins connected to the rotary encoder
const int re_pinPush = 4;     // encoder pushbutton pin
const int re_pinA = 3;        // encoder A pin
const int re_pinB = 2;        // encoder B pin

// define microcontroller pins that control the DDS-60
const byte DDS_FQ_UD = 16;    // connected to AD9851 device select pin
const byte DDS_W_CLK = 15;    // connected to AD9851 clock pin
const byte DDS_DATA = 14;     // connected to AD9851 D7 (serial data) pin 

// Define the address in EEPROM of various things.
#define NEXT_SLOT(a)    ((a) + sizeof(a))

// number of frequency save slots in EEPROM
const int NumSaveSlots = 10;

const int EepromFreq = 0;
const int EepromSelDigit = NEXT_SLOT(EepromFreq);
const int EepromVfoClockOffset = NEXT_SLOT(EepromSelDigit);
const int EepromContrast = NEXT_SLOT(EepromVfoClockOffset);
const int EepromBrightness = NEXT_SLOT(EepromContrast);
const int EepromHoldClickTime = NEXT_SLOT(EepromBrightness);
const int EepromDClickTime = NEXT_SLOT(EepromHoldClickTime);
const int EepromVoltsCalibrate = NEXT_SLOT(EepromDClickTime);
const int EepromSaveFreqBase = NEXT_SLOT(EepromVoltsCalibrate);
const int EepromSaveOffsetBase = EepromSaveFreqBase + NumSaveSlots*sizeof(Frequency);

//-----
// Data and values used by the LCD code.
//-----

// max and min frequency showable
const Frequency MaxFreq = 60000000L;
const Frequency MinFreq = 1000000L;

// number of digits in the frequency display
const int NumFreqChars = 8;

// address in display CGRAM for definable and other characters
const int SelectChar = 0;     // shows 'underlined' decimal digits (dynamic, 0 to 9)
const int SpaceChar = 1;      // shows an 'underlined' space character
const int InUseChar = 2;      // shows a right-facing arrow
const int BatteryChar = 3;    // shows the appropriate battery symbol

const int AllsetChar = 0xff;  // the 'all bits set' char in display RAM, used for 'bar' display

// define the numeric digits and space with selection underline
byte sel0[8]  = {0x0e,0x11,0x13,0x15,0x19,0x11,0x0e,0x1f};
byte sel1[8]  = {0x04,0x0c,0x04,0x04,0x04,0x04,0x0e,0x1f};
byte sel2[8]  = {0x0e,0x11,0x01,0x02,0x04,0x08,0x1f,0x1f};
byte sel3[8]  = {0x1f,0x02,0x04,0x02,0x01,0x11,0x0e,0x1f};
byte sel4[8]  = {0x02,0x06,0x0a,0x12,0x1f,0x02,0x02,0x1f};
byte sel5[8]  = {0x1f,0x10,0x1e,0x01,0x01,0x11,0x0e,0x1f};
byte sel6[8]  = {0x06,0x08,0x10,0x1e,0x11,0x11,0x0e,0x1f};
byte sel7[8]  = {0x1f,0x01,0x02,0x04,0x08,0x08,0x08,0x1f};
byte sel8[8]  = {0x0e,0x11,0x11,0x0e,0x11,0x11,0x0e,0x1f};
byte sel9[8]  = {0x0e,0x11,0x11,0x0f,0x01,0x02,0x0c,0x1f};
byte selsp[8] = {0x00,0x00,0x00,0x00,0x00,0x00,0x00,0x1f};

// array of references to the 11 'selected' characters (0 to 9 plus space)
byte *sel_digits[] = {sel0, sel1, sel2, sel3, sel4, sel5, sel6, sel7, sel8, sel9, selsp};
const int SpaceIndex = 10;

// define the "in use" character
byte in_use_char[8] = {0x10,0x18,0x1c,0x1e,0x1c,0x18,0x10,0x00};

//-----
// battery symbols
//-----

byte battunder[8] = {0x0e,0x1b,0x11,0x11,0x11,0x11,0x11,0x11};
byte batt00[8]    = {0x0e,0x1b,0x11,0x11,0x11,0x11,0x11,0x1f};
byte batt20[8]    = {0x0e,0x1b,0x11,0x11,0x11,0x11,0x1f,0x1f};
byte batt40[8]    = {0x0e,0x1b,0x11,0x11,0x11,0x1f,0x1f,0x1f};
byte batt60[8]    = {0x0e,0x1b,0x11,0x11,0x1f,0x1f,0x1f,0x1f};
byte batt80[8]    = {0x0e,0x1b,0x11,0x1f,0x1f,0x1f,0x1f,0x1f};
byte batt100[8]   = {0x0e,0x1b,0x1f,0x1f,0x1f,0x1f,0x1f,0x1f};
byte battover[8]  = {0x1f,0x1f,0x1f,0x1f,0x1f,0x1f,0x1f,0x1f};
byte battnone[8]  = {0x04,0x06,0x0d,0x15,0x14,0x10,0x00,0x00}; // a USB logo (sort of)

// array of references to the 9 'battery symbol' characters
byte *batt_syms[] = {battunder, batt00, batt20, batt40, batt60, batt80, batt100, battover, battnone};

// map select_offset to frequency bump values
Frequency offset2bump[] = {1,           // offset = 0
                           10,          // 1
                           100,         // 2
                           1000,        // 3
                           10000,       // 4
                           100000,      // 5
                           1000000,     // 6
                           10000000,    // 7
                           100000000};  // 8

// string holding one entire blank row
char *BlankRow = (char *) "                ";

// default frequency plus LCD contrast & brightness, etc
const Frequency DefaultFrequency = MinFreq;
const int DefaultVfoClockOffset = 0;
const UINT DefaultSelDigit = 2;
const UINT DefaultLcdContrast = 0;
const UINT DefaultLcdBrightness = 150;
const UINT DefaultVoltsCalibrate = 1000;

//-----
// Events and the event queue.
//-----

// define the VFOevents
enum Event
{
  vfo_None,
  vfo_RLeft,
  vfo_RRight,
  vfo_DnRLeft,
  vfo_DnRRight,
  vfo_Click,
  vfo_HoldClick,
  vfo_DClick,
};

// define the length of the event queue
const int EventQueueLength = 10;

//-----
// Miscellaneous.
//-----

// number of measurements in the moving average of voltage
#define AVG_SIZE      5

// the average measured voltage
float AverageVoltage = 0.0;

// milliseconds delay between measuring battery voltage
const long MeasureVoltageDelay = 1000;

// number of voltage measure periods before report (if wanted in DEBUG)
const long ReportVoltageDelay = 60;   // once every minute

// value from the circuit: (R12 + R13)/R13
// this can be calibrated in the menus, see below
#define VDIV_RATIO    32.11/9.90

// the voltage calibration is the ratio of VoltsCalibrate to VCALIBBASE
#define VCALIBBASE    1000

// stuff for the calibrate action
const int MinClockOffset = -32000;
const int MaxClockOffset = +32000;
const int MaxOffsetDigits = 5;

// battery voltage limits
const float OverVoltage = 8.30;   // battery voltage for CHARGING & FULL
const float MaxVoltage = 7.90;    // battery voltage for "100% full"
const float MinVoltage = 6.50;    // battery voltage for "0% full"
                                  // BMS disconnects at around 6.40v
const float NoBattVoltage = 5.5;  // if at or below this, no battery

// voltage calibration limits
const UINT MinVoltsCalibrate = 100;
const UINT MaxVoltsCalibrate = 2000;

// macro to get number of elements in an array
#define ALEN(a)    (sizeof(a)/sizeof((a)[0]))

// buffer, etc, to gather external command strings
#define MAX_COMMAND_LEN   16
#define COMMAND_END_CHAR    ';'
char CommandBuffer[MAX_COMMAND_LEN+1];
int CommandIndex = 0;

// buffer to assemble frequency as a string
const int FreqBufferLen = 16;
char FreqBuffer[FreqBufferLen];

// time when click becomes a "hold click" (milliseconds)
// the delay is configurable in the UI
const int MinHoldClickTime = 100;     // min configurable time
const int MaxHoldClickTime = 1000;    // max configurable time
const int DefaultHoldClickTime = 500; // default time

// time when click becomes a "double click" (milliseconds)
// the delay is configurable in the UI
const int MinDClickTime = 100;        // min configurable time
const int MaxDClickTime = 1000;       // max configurable time
const int DefaultDClickTime = 300;    // default time

//##############################################################################
// The VFO state variables and typedefs
//
// The data here will be saved in EEPROM at various times.
// Code for the device will contain internal variables that aren't saved.
//##############################################################################

bool Aborted = false;       // not aborted, yet

SelOffset VfoSelectDigit;   // selected column index, zero at the right

// the voltage measurement calibration
UINT VoltsCalibrate = DefaultVoltsCalibrate;

typedef byte VFOEvent;

int LcdContrast = DefaultLcdContrast;
int LcdBrightness = DefaultLcdBrightness;

// adjustment value for DDS-60 (set in 'Calibrate' menu)
int VfoClockOffset = DefaultVfoClockOffset;

// global pointing to symbol for current battery state
byte *BatterySymbol = battunder;

//##############################################################################
// RE internal variables.
//##############################################################################

// internal variables
UINT ReHoldClickTime = DefaultHoldClickTime;
UINT ReDClickTime = DefaultDClickTime;

bool re_rotation = false;     // true if rotation occurred while knob down
bool re_down = false;         // true while knob is down
ULONG re_down_time = 0;       // milliseconds when knob is pressed down
ULONG last_click = 0;         // time when last single click was found

// expecting rising edge on pinA - at detent
volatile byte aFlag = 0;

// expecting rising edge on pinA - at detent
volatile byte bFlag = 0;

//##############################################################################
// Utility routines
//##############################################################################

// Should restart Teensy 3, will also disconnect USB during restart
#define RESTART_ADDR       0xE000ED0C
#define READ_RESTART()     (*(volatile uint32_t *)RESTART_ADDR)
#define WRITE_RESTART(val) ((*(volatile uint32_t *)RESTART_ADDR) = (val))

/* restart the Teensy, without invoking bootloader. */
void restart(void)
{
  Serial.print("Restarting ...");
  delay(500);
  WRITE_RESTART(0x5FA0004);  
}

/* reboot the Teensy, invoking bootloader. */
void reboot(void)
{
  Serial.print("Rebooting ...");
  delay(500);
  _reboot_Teensyduino_();
}

//----------------------------------------
// Overwrite everything in the EEPROM.
//----------------------------------------

#if INIT_EEPROM != 0
void initialize_eeprom()
{
  Serial.print("Erasing EVERYTHING in EEPROM!\n");
  delay(3000);
  EEPROM.put(EepromFreq, DefaultFrequency);
  EEPROM.put(EepromSelDigit, DefaultSelDigit);
  EEPROM.put(EepromVfoClockOffset, DefaultVfoClockOffset);
  EEPROM.put(EepromContrast, DefaultLcdContrast);
  EEPROM.put(EepromBrightness, DefaultLcdBrightness);
  EEPROM.put(EepromHoldClickTime, DefaultHoldClickTime);
  EEPROM.put(EepromDClickTime, DefaultDClickTime);
  EEPROM.put(EepromVoltsCalibrate, DefaultVoltsCalibrate);

  for (int i = 0; i < NumSaveSlots; ++i)
  {
    int addr = EepromSaveFreqBase + i * sizeof(Frequency);
    EEPROM.put(addr, (Frequency) 0);
    addr = EepromSaveOffsetBase + i * sizeof(SelOffset);
    EEPROM.put(addr, (SelOffset) 0);
  }
}
#endif

//----------------------------------------
// Calculate the moving average.
//     new_measurement  the new measurement to average
// Returns the current moving average.
//----------------------------------------

float moving_average(float new_measurement)
{
  return ((AVG_SIZE - 1) * AverageVoltage + new_measurement) / AVG_SIZE;
}

//----------------------------------------
// Abort the program.
// Tries to tell the world what went wrong.
//     msg  address of error string
// Only first LcdNumRows*LcdNumCols chars of message is displayed on LCD.
//----------------------------------------

void DV_abort(const char *msg)
{
  char buf[LcdNumCols*LcdNumRows+1];
  char *ptr = buf;
  
  Aborted = true;   // set "Aborted" flag

  // print error on console (maybe)
  Serial.printf("message=%s\nTeensy is aborted!\n", msg);

  // truncate/pad message to LcdNumRows * LcdNumCols chars
  for (int i = 0; i < LcdNumCols*LcdNumRows; ++i)
    *ptr++ = ' ';
  *ptr = '\0';
  
  strncpy(buf, msg, LcdNumCols*LcdNumRows);
  if (strlen(msg) < LcdNumCols*LcdNumRows)
    strncpy(buf + strlen(msg), "                                ",
            LcdNumCols*LcdNumRows - strlen(msg));

  // show what we can on the display
  lcd.clear();
  for (int i = 0; i < LcdNumRows; ++i)
  {
    lcd.setCursor(0, i);
    lcd.print(buf + i*LcdNumCols);
  }
}

//----------------------------------------
// Convert an event number to a display string.
//----------------------------------------

const char *event2display(VFOEvent event)
{
  switch (event)
  {
    case vfo_None:      return "vfo_None";
    case vfo_RLeft:     return "vfo_RLeft";
    case vfo_RRight:    return "vfo_RRight";
    case vfo_DnRLeft:   return "vfo_DnRLeft";
    case vfo_DnRRight:  return "vfo_DnRRight";
    case vfo_Click:     return "vfo_Click";
    case vfo_HoldClick: return "vfo_HoldClick";
    case vfo_DClick:    return "vfo_DClick";
  }
  
  return "UNKNOWN EVENT";
}

const char *debug2display(int debug)
{
  switch (debug)
  {
    case DEBUG_DDS:   return "DEBUG_DDS";
    case DEBUG_FREQ:  return "DEBUG_FREQ";
    case DEBUG_MENU:  return "DEBUG_MENU";
    case DEBUG_EVENT: return "DEBUG_EVENT";
    case DEBUG_ACT:   return "DEBUG_ACT";
    case DEBUG_RE:    return "DEBUG_RE";
    case DEBUG_INT:   return "DEBUG_INT";
    case DEBUG_DISP:  return "DEBUG_DISP";
    case DEBUG_BATT:  return "DEBUG_BATT";
    case DEBUG_MISC:  return "DEBUG_MISC";
  }

  return "UNKNOWN DEBUG";
}

//----------------------------------------
// Dump the DEBUG word to the serial port.
//     debug  the debug word to interpret into English
//----------------------------------------

void decode_debug_levels(int debug)
{
  Serial.printf("DEBUG is defined as %06x:\n", debug);

  // shift a single bit left for 16 places
  for (int bit = 1; bit <= 0xffff; bit <<= 1)
  {
    if (debug & bit)
      Serial.printf("  %s\tbit is set: %06x\n", debug2display(bit), bit);
  }
}

//----------------------------------------
// Show the credits on the LCD.
//----------------------------------------

void show_credits(bool minor)
{
  lcd.clear();
  lcd.setCursor(0, 0);
  lcd.print(ProgramName);
  lcd.print(" ");
  lcd.print(Version);
  if (minor)
  {
    lcd.print(MinorVersion);
  }
  lcd.setCursor(LcdNumCols-strlen(Callsign), 1);
  lcd.print(Callsign);
}

//----------------------------------------
// Display a simple banner on the LCD.
//----------------------------------------

void banner(void)
{
  show_credits(false);
  delay(500);    // wait a bit

  // do a fade out, clear screen then normal brightness
  for (int i = LcdBrightness; i; --i)
  {
    analogWrite(mc_Brightness, i);
    delay(10);
  }
  lcd.clear();
  delay(100);
  analogWrite(mc_Brightness, LcdBrightness);
}

void fade_out(void)
{
  // do a fade out, clear screen then normal brightness
  for (int i = LcdBrightness; i; --i)
  {
    analogWrite(mc_Brightness, i);
    delay(10);
  }
  lcd.clear();
  delay(300);
  analogWrite(mc_Brightness, LcdBrightness);
}

//----------------------------------------
// Function to convert a long integer into an array of byte digit values.
//     buf      address of buffer for byte results
//     bufsize  size of the 'buf' buffer
//     value    the Frequency value to convert
// The function won't overflow the given buffer, it will truncate at the left.
// For example, given the value 1234 and a buffer of length 7, will fill the
// buffer with 0001234.  Given 123456789 and length 7 it will fill with 3456789.
//
// Each byte in the buffer is a number in [0, 9], NOT ['0', '9'].
// The resultant buffer does NOT have a terminating '\0'!
//----------------------------------------

void ulong2buff(char *buf, int bufsize, long value)
{
  char *ptr = buf + bufsize - 1;    // rightmost char in 'buf'

  for (int i = 0; i < bufsize; ++i)
  {
    int rem = value % 10;

    value = value / 10;
    *ptr-- = char(rem);     // FIXME: don't require char()?
  }
}

//----------------------------------------
// Convert a numeric mode to a display string.
//----------------------------------------

const char *mode2display(Mode mode)
{
  switch (mode)
  {
    case vfo_Standby: return "standby";
    case vfo_Online:  return "ONLINE";
  }

  return "UNKNOWN MODE";
}

//----------------------------------------
// Convert a string to uppercase in situ.
//----------------------------------------

void str2upper(char *str)
{
  while (*str)
  {
    *str = toupper(*str);
    ++str;
  }
}

//##############################################################################
// Code to save/restore in EEPROM.
//##############################################################################

//----------------------------------------
// Save VFO state to EEPROM.
// Everything except slot data.
//----------------------------------------

void save_to_eeprom(void)
{
  EEPROM.put(EepromFreq, VfoFrequency);
  EEPROM.put(EepromSelDigit, VfoSelectDigit);
  EEPROM.put(EepromVfoClockOffset, VfoClockOffset);
  EEPROM.put(EepromBrightness, LcdBrightness);
  EEPROM.put(EepromContrast, LcdContrast);
  EEPROM.put(EepromHoldClickTime, ReHoldClickTime);
  EEPROM.put(EepromDClickTime, ReDClickTime);
  EEPROM.put(EepromVoltsCalibrate, VoltsCalibrate);
}

//----------------------------------------
// Restore VFO state from EEPROM.
// Everything except slot data.
//----------------------------------------

void restore_from_eeprom(void)
{
  EEPROM.get(EepromFreq, VfoFrequency);
  EEPROM.get(EepromSelDigit, VfoSelectDigit);
  EEPROM.get(EepromVfoClockOffset, VfoClockOffset);
  EEPROM.get(EepromBrightness, LcdBrightness);
  EEPROM.get(EepromContrast, LcdContrast);
  EEPROM.get(EepromHoldClickTime, ReHoldClickTime);
  EEPROM.get(EepromDClickTime, ReDClickTime);
  EEPROM.get(EepromVoltsCalibrate, VoltsCalibrate);
}

//----------------------------------------
// Given slot number, return freq/offset.
//     freq    pointer to Frequency item to be updated
//     offset  pointer to selection offset item to be updated
//----------------------------------------

void get_slot(int slot_num, Frequency &freq, SelOffset &offset)
{
  int freq_address = EepromSaveFreqBase + slot_num * sizeof(Frequency);
  int offset_address = EepromSaveOffsetBase + slot_num * sizeof(SelOffset);

  EEPROM.get(freq_address, freq);
  EEPROM.get(offset_address, offset);
}

//----------------------------------------
// Put frequency/offset into given slot number.
//     freq    pointer to Frequency item to be saved in slot
//     offset  pointer to selection offset item to be saved in slot
//----------------------------------------

void put_slot(int slot_num, Frequency freq, SelOffset offset)
{
  int freq_address = EepromSaveFreqBase + slot_num * sizeof(Frequency);
  int offset_address = EepromSaveOffsetBase + slot_num * sizeof(SelOffset);

  EEPROM.put(freq_address, freq);
  EEPROM.put(offset_address, offset);
}

//----------------------------------------
// Print all EEPROM saved data to console.
//----------------------------------------

#define DELAY_MS 100  // not sure why we need a delay to print reliably
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
void loop(void)
{
  // if DigitalVFO is aborted, do nothing
  // We used to just loop in abort(), but this made reboots difficult
  if (Aborted)
    return;
    
  // do any external commands
  do_external_commands();
  
  // handle all events in the queue
  handle_RE_events();

  // check the battery
  measure_battery();
  
  // update the display
  display_sel_value(VfoFrequency, VfoSelectDigit, NumFreqChars, LcdNumCols - NumFreqChars - 2 - 2, 0);
  display_battery();

  // if online, update DDS-60 and write changes to EEPROM
  if (VfoMode == vfo_Online)
  {
    dds_update(VfoFrequency);
    save_to_eeprom();   // only writes if value(s) different
  }
}

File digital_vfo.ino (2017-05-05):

////////////////////////////////////////////////////////////////////////////////
// A digital VFO using the DDS-60 card.
//
// The VFO will generate signals in the range 1.000000MHz to 30.000000MHz
// with a step of 1Hz.
//
// The interface will be a single rotary encoder with a built-in pushbutton.
// The frequency display will have a 'selected' digit which can be moved left
// and right by pressing the encoder knob and twisting left or right.
// Turning the encoder knob will increment or decrement the selected digit by 1
// with overflow or underflow propagating to the left.
////////////////////////////////////////////////////////////////////////////////

#include <LiquidCrystal.h>
#include <EEPROM.h>


// display constants - below is for ubiquitous small HD44780 16x2 display
#define NUM_ROWS        2
#define NUM_COLS        16

// define data pins we connect to the LCD
static byte lcd_RS = 7;
static byte lcd_ENABLE = 8;
static byte lcd_D4 = 9;
static byte lcd_D5 = 10;
static byte lcd_D6 = 11;
static byte lcd_D7 = 12;

// define data pins used by the rotary encoder
static int re_pinA = 2;     // encoder A pin
static int re_pinB = 3;     // encoder B pin
static int re_pinPush = 4;  // encoder pushbutton pin

// max and min frequency showable
#define MAX_FREQ        30000000L
#define MIN_FREQ        1000000L

// size of frequency display in chars (30MHz is maximum frequency)
#define MAX_FREQ_CHARS  8

// address in display CGRAM for definable characters
#define SELECT_CHAR     0   // shows 'underlined' decimal digits (dynamic, 0 to 9)
#define SPACE_CHAR      1   // shows an 'underlined' space character
# FIXME use only one CGRAM character for 0 to 9 AND space

// define the numeric digits and space with selection underline
byte sel0[8] = {0xe,0x11,0x13,0x15,0x19,0x11,0xe,0x1f};
byte sel1[8] = {0x4,0xc,0x4,0x4,0x4,0x4,0xe,0x1f};
byte sel2[8] = {0xe,0x11,0x1,0x2,0x4,0x8,0x1f,0x1f};
byte sel3[8] = {0x1f,0x2,0x4,0x2,0x1,0x11,0xe,0x1f};
byte sel4[8] = {0x2,0x6,0xa,0x12,0x1f,0x2,0x2,0x1f};
byte sel5[8] = {0x1f,0x10,0x1e,0x1,0x1,0x11,0xe,0x1f};
byte sel6[8] = {0x6,0x8,0x10,0x1e,0x11,0x11,0xe,0x1f};
byte sel7[8] = {0x1f,0x1,0x2,0x4,0x8,0x8,0x8,0x1f};
byte sel8[8] = {0xe,0x11,0x11,0xe,0x11,0x11,0xe,0x1f};
byte sel9[8] = {0xe,0x11,0x11,0xf,0x1,0x2,0xc,0x1f};
byte selspace[8] = {0x0,0x0,0x0,0x0,0x0,0x0,0x0,0x1f};

// array of references to the 11 'selected' characters (0 to 9 plus space)
byte *sel_digits[] = {sel0, sel1, sel2, sel3, sel4, sel5, sel6, sel7, sel8, sel9, selspace};
#define SPACE_INDEX   10

// map select_offset to bump values
unsigned long offset2bump[] = {1,           // offset = 0
                               10,          // 1
                               100,         // 2
                               1000,        // 3
                               10000,       // 4
                               100000,      // 5
                               1000000,     // 6
                               10000000,    // 7
                               100000000};  // 8

// values updated by rotary encoder interrupt routines
volatile byte encoderCount = 0;

// define the display connections
LiquidCrystal lcd(lcd_RS, lcd_ENABLE, lcd_D4, lcd_D5, lcd_D6, lcd_D7);

// old values of 're_delta' and 're_position'
int oldEncOffset = 1;
byte oldEncPos = 180;


////////////////////////////////////////////////////////////////////////////////
// The VFO state variables
////////////////////////////////////////////////////////////////////////////////

unsigned long VfoFrequency;   // VFO frequency (Hz)
int VfoSelectDigit;           // selected digit, indexed from zero at right


////////////////////////////////////////////////////////////////////////////////
// Utility routines for the display.
////////////////////////////////////////////////////////////////////////////////

//------------------------------------------------------------------------------
// Function to convert an unsigned long into an array of byte digit values.
//     buf      address of buffer for byte results
//     bufsize  size of the 'buf' buffer
//     value    the unsigned long value to convert
// The function won't overflow the given buffer, it will truncate at the left.
// 
// For example, given the value 1234 and a buffer of length 7, will fill the
// buffer with 0001234.  Given 123456789 it will fill with 3456789.
//------------------------------------------------------------------------------
void ltobbuff(char *buf, int bufsize, unsigned long value)
{
  char *ptr = buf + bufsize - 1;

  for (int i = 0; i < bufsize; ++i)
  {
    int rem = value % 10;
    
    value = value / 10;
    *ptr-- = char(rem);
  }
}

//------------------------------------------------------------------------------
// Print the frequency on the display with selected colum underlined.
//     freq  the frequency to display
//     col   the selection offset of digit to underline
//           (0 is rightmost digit, increasing to the left)
// The row and columns used to show frequency digits are defined elsewhere.
// A final "Hz" is written. 
//------------------------------------------------------------------------------
void print_freq(unsigned long freq, int col)
{
  char buf [MAX_FREQ_CHARS];
  int index = MAX_FREQ_CHARS - col - 1;
  bool lead_zero = true;

  ltobbuff(buf, MAX_FREQ_CHARS, freq);

  lcd.createChar(SELECT_CHAR, sel_digits[int(buf[index])]);
  lcd.setCursor(NUM_COLS - MAX_FREQ_CHARS - 2, 0);
  for (int i = 0; i < MAX_FREQ_CHARS; ++i)
  {
    int char_val = buf[i];

    if (char_val != 0)
        lead_zero = false;

    if (lead_zero)
    {
      if (index == i)
        lcd.write(byte(SPACE_CHAR));
      else
        lcd.write(" ");
    }
    else
    {
      if (index == i)
        lcd.write(byte(SELECT_CHAR));
      else
        lcd.write(char_val + '0');
    }
  }
  
  lcd.write("Hz");
}

////////////////////////////////////////////////////////////////////////////////
// Interrupt driven rotary encoder interface.
////////////////////////////////////////////////////////////////////////////////

// states for the encode machine
static int re_stateUp = 0;
static int re_stateDown = 1;
volatile int re_state = 0;

////////////////////////////
// internal state variables
////////////////////////////

// expecting rising edge on pinA - at detent
volatile byte aFlag = 0;

// expecting rising edge on pinA - at detent
volatile byte bFlag = 0;

// this variable stores our current value of encoder position.
// Change to int or uin16_t instead of byte if you want to record a larger range than 0-255
volatile long re_delta = 0;

// stores latest offset value
volatile int re_position = 0;
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

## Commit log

2017-05-05 Add FIXME about only using *one* CGRAM character
    [digital_vfo.ino]
2017-05-06 Removed interrupt disable
2017-05-09 Indicate that slot freq is the current freq. Close #2
2017-05-09 Fixed bug when decreasing freq
    [DigitalVFO.ino]
2017-05-15 Working on save/restore/delete slot menus
2017-05-18 Now using Serial.printf()
2017-05-18 Better reset option during startup, close #6
    [DigitalVFO.ino]
2017-05-18 Added 'reset' menu option - close #7
    [DigitalVFO.ino]
2017-05-20 Clean up and implemented 'calibrate' submenu
2017-05-21 Rearranged a lot of code, better interrupt handling
2017-05-24 Fixed issue #16 - Slots submenu
    [DigitalVFO.ino]
2017-05-28 Spelling error, forcing B/C to debug display
    [DigitalVFO.ino]
2017-06-09 Removed debug prints
2017-06-09 Doc on calibration
2017-06-15 Added schematic PNG
2017-06-15 Included schematic
2017-06-15 Sigh. Added missing wire
2017-11-20 Added contrast voltage smoothing in circuit
2017-11-26 Contrast works with USB or 9v power
2017-12-05 Documented the SCH/PCB files
2017-12-05 Added PCB/SCH files
2018-01-05 Initial commit -f KiCad files
    [DigitalVFO-B.Cu.gbl, DigitalVFO-B.Mask.gbs, DigitalVFO-B.SilkS.gbo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]
2018-01-05 Added *production* schematic
2018-01-05 Added KiCad notes and production files
2018-01-10 Code changed to match 1.1 schematic
2018-01-10 Added PNG for new schematic
2018-01-13 Fixed confusion around RE socket
    [DigitalVFO.kicad_pcb, DigitalVFO.sch]
2018-01-13 Restore only good freq from slot - close #21
2018-01-14 Added 'ID;' command to identify device
2018-02-12 Changing footprints and smaller board
    [DigitalVFO.kicad_pcb, DigitalVFO.sch]
2018-02-23 Working on new PCB
    [DigitalVFO.kicad_pcb, DigitalVFO.sch]
2018-02-23 Restart working, reboot isn't
    [DigitalVFO.ino]
2018-02-23 New footprint
2018-03-18 New footprints
2018-03-18 Almost ready with v1.2
    [DigitalVFO.kicad_pcb, DigitalVFO.sch]
2018-03-23 Ignore KiCAD *bak files
2018-03-23 Final version?
    [DigitalVFO.kicad_pcb, DigitalVFO.sch]
2018-03-29 Removed old project
    [DigitalVFO-B.Cu.gbl, DigitalVFO-B.Mask.gbs, DigitalVFO-B.SilkS.gbo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]
2018-03-29 V1.2 schematic
2018-03-29 New KiCad project
    [DigitalVFO.kicad_pcb, DigitalVFO.sch]
2018-04-27 Version 1.4
    [DigitalVFO-B.Cu.gbl, DigitalVFO-B.Mask.gbs, DigitalVFO-B.SilkS.gbo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]
2018-04-29 v1.5 - more compact layout
    [DigitalVFO-B.Cu.gbr, DigitalVFO-B.Mask.gbr, DigitalVFO-B.SilkS.gbr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]
2018-05-19 Ignore everything in the 'gerber' directory
2018-05-20 Additional footprints
2018-05-20 Added testpoints and 1602A mount holes
    [DigitalVFO.kicad_pcb, DigitalVFO.sch]
2018-05-20 Minor fix to display - don't show old text on reload
    [DigitalVFO.ino]
2018-05-20 Moved track away from LCD mount hole
    [DigitalVFO.kicad_pcb]
2018-05-20 Added voltage measurement and battery indicator
2018-05-20 Made battery stuff optional compile
2018-05-21 Fixed bug setting brightness
    [DigitalVFO.ino]
2018-05-21 Cleanup and better battery reporting
2018-06-04 Better device checking
2018-06-23 Added newer schematic/PCB pictures
2018-07-01 Faffing around trying to recognize serial port from USB device.
2018-07-01 Meaningless meanderings
    [DigitalVFO.kicad_pcb, DigitalVFO.sch]
2018-07-03 Bumped 'build' number by one, ready for battery changes
2018-07-09 Sort of calibrated the battery
2018-07-11 Calibrated the battery monitoring, a bit
2018-07-14 Filtering on Teensy
2018-07-14 Show all devices
2018-07-14 Plot charge/discharge curves
2018-07-15 Calibrated a little more, better battery symbol
2018-07-15 Better battery test monitoring software
2018-07-16 Collect voltage data
2018-07-16 Better track layout
    [DigitalVFO.kicad_pcb]
2018-07-18 Fixed BUG in battery reporting code
    [DigitalVFO.ino]
2018-07-18 Cleaned up voltage measuring code
2018-07-18 Added back silkscreen for test points
    [DigitalVFO.kicad_pcb, DigitalVFO.sch]
2018-07-18 Removed routines replaced by stdlib code
    [DigitalVFO.ino]
2018-09-10 Fixed problem with second immediate run not working
    [serial_test.py]
2018-09-11 Added the Arduino sketch to test serial comms
2018-10-12 Updated callsign, voltage now averaged
2018-11-23 Updated the PCB
    [DigitalVFO.kicad_pcb, DigitalVFO.sch]
2019-02-22 Setting a more accurate percent battery figure
2019-02-24 Putting in Voltage Calibrate
2019-02-24 KiCad update?
2019-02-25 Debugging freq calibrate save problem
    [DigitalVFO.ino]
2019-02-25 Debugging volts calibrate save problem
    [DigitalVFO.ino]
2019-02-27 Added voltage calibration
2019-02-28 Volts calibrate done, plus cleanup.
2019-03-02 Added pic of finished device
2019-03-03 Testing the clone circuit
2019-03-12 Fixed problem not updating DDS-60 frequency
    [DigitalVFO.ino]
2019-04-08 Small changes
    [DigitalVFO.sch]
2019-05-05 Generated images of 1.5 schematic
2019-07-06 Tried different 'cursor' presentation, failed
    [DigitalVFO.ino]
2020-09-17 Just fiddling, checking battery voltage
